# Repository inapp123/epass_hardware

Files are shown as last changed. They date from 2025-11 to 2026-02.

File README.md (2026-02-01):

# 明日方舟电子通行认证 PCB

一款类似手机游戏《明日方舟》中的通行认证的电子挂牌。

当前版本：Ver0.6

本项目存放通行认证的PCB电路设计。PCB为群友“你说得对”使用嘉立创EDA进行Layout。

USB布线比我的kicad好，而且只需要二层板。如果你需要查看原始kicad设计文件，请在左上角将分支切换为：onlykicad。

设计。工艺参数参考嘉立创二层板，设计厚度为1mm。

## 文件

* 阻容封装0402：
  * ProDoc__v0.6_0402_2026-01-24.epro2 PCB设计文件
  * InteractiveBOM_0.6_0402_2026-1-24.html 交互式BOM

* 阻容封装0603：
  * ProDoc__v0.6_0603_2026-01-24.epro2 PCB设计文件
  * InteractiveBOM_0.6_0603_2026-1-24.html 交互式BOM

**最新嘉立创专业版打开，不知道什么意思就打0603**

## BOM链接

感谢 星语Studio 整理！

0603版本：https://docs.qq.com/sheet/DTUNVSW9USXBOS3VJ?nlc=1&tab=8444d8
0402版本：https://docs.qq.com/sheet/DTUNVSW9USXBOS3VJ?nlc=1&tab=msd95g

## 开源协议

CERN Open Hardware Licence Version 2 - Permissive

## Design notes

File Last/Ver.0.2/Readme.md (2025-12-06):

# ⓘ 此为旧版本文件(ver0.2)

![[image-20251119004316917.png]]

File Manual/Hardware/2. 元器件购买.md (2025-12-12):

# 此文档用于解答关于元件购买的问题

## 按钮
2 * 4 * 3.5 小贝贝(指BOM表链接，若在别处购买请按照实际尺寸)
![[2_1.png]]

## 肖特基二极管
1N5819WS SS14 **SOD-323**

### ⚠务必注意封装是 SOD-323 (非常重要，已有N人买错)
![[2_2.png]]

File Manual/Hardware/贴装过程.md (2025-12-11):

# 电子通行证制作指南

版本：V0.3.1

## 在一切开始之前...
> 本项目包含QFN表面贴装器件，如果您此前没有使用表面贴装器件进行DIY项目的经验，建议您通过其他较简单的项目练习贴装，**不要直接开始制作**。

## 除了bom表中的器件外，应该准备的工具:

### 焊接工具

| 工具名称 | 说明 |
| --- | --- |
| 锡膏 | 锡膏温度不建议过高，使用熔点在173-213摄氏度之间的中温锡即可 |
| 锡丝 | 焊接直插器件时比锡膏舒服，建议熔点同上 |
| 助焊剂 | 弥补焊接技术不足的好工具，一般使用针管装smt焊油 |
| 洗板水 | 如果出现奇怪的短路问题，请使用洗板水洗干净pcb再测试，有条件的可以使用超声波清洗仪 |
| 电烙铁 | 一把正版的黄花电烙铁足矣，温度不宜过高，开在300度左右即可 |
| 热风枪 | 有条件最好选用868D(气泵式),858D(风扇式)加热不太均匀 |
| 加热台 | reserved |
| 镊子 | 为了舒服地贴装，最好有直头镊子和弯头镊子，镊子可能被助焊剂污染，当镊子明显与器件粘连时，用酒精和洗板水清洗镊尖 |
| 放大镜 | 最好是玻璃放大镜，帮你看清微小的焊点 |
| 吸锡带 | 当焊盘上出现了过多的锡，使用它去除。你也可以使用吸锡器，但是需要一些练习 |
| 高温胶带 | 保护/绝缘/临时固定，pcb上的万用胶带 |
| *漆包线 | 非必选项，但是遇到意外时它很有用 |

### 调试工具

| 工具名称 | 说明 |
| --- | ----- |
| 万用表 | reserved |
| USB转串口 | 没有此工具将无法在屏幕不工作的状态下调试设备 |

### 开始贴装之前...

* 本项目包含的器件体积较小，因此对于很多小型器件，不要加入大量的锡，否则可能会短路。对于0603器件，轻按针管挤出一点点锡到焊盘上即可。
* 遇到引脚较密集的器件，合理使用助焊剂增加锡融化后的表面张力让焊接变得方便。
* 不要使用过高的温度/过长的时间/局部加热焊接芯片，连接器等温度敏感器件，焊接时匀速顺时针/逆时针均匀加热器件。
* 如果无法使用烙铁焊接贴片器件就使用风枪焊接，不要强行焊接导致焊盘脱落。
* 使用镀锡pcb板时，请不要提前开封pcb，否则可能导致焊盘氧化导致大量虚焊。

## 贴装

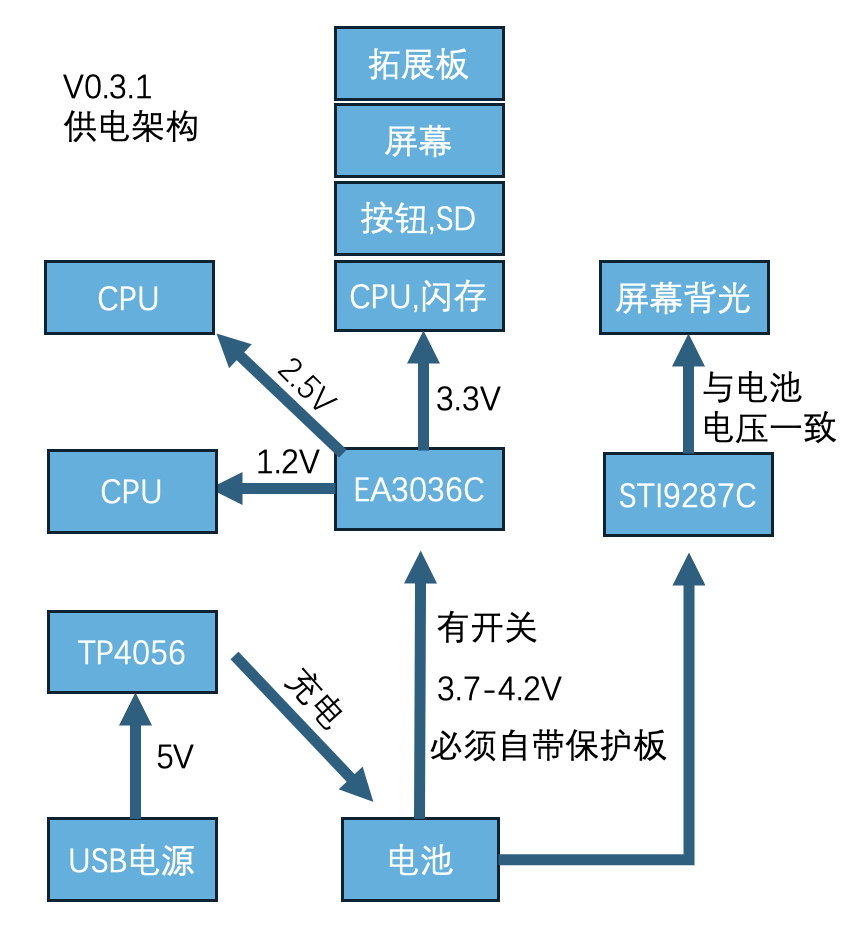
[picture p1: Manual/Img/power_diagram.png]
V0.3.1 电源架构


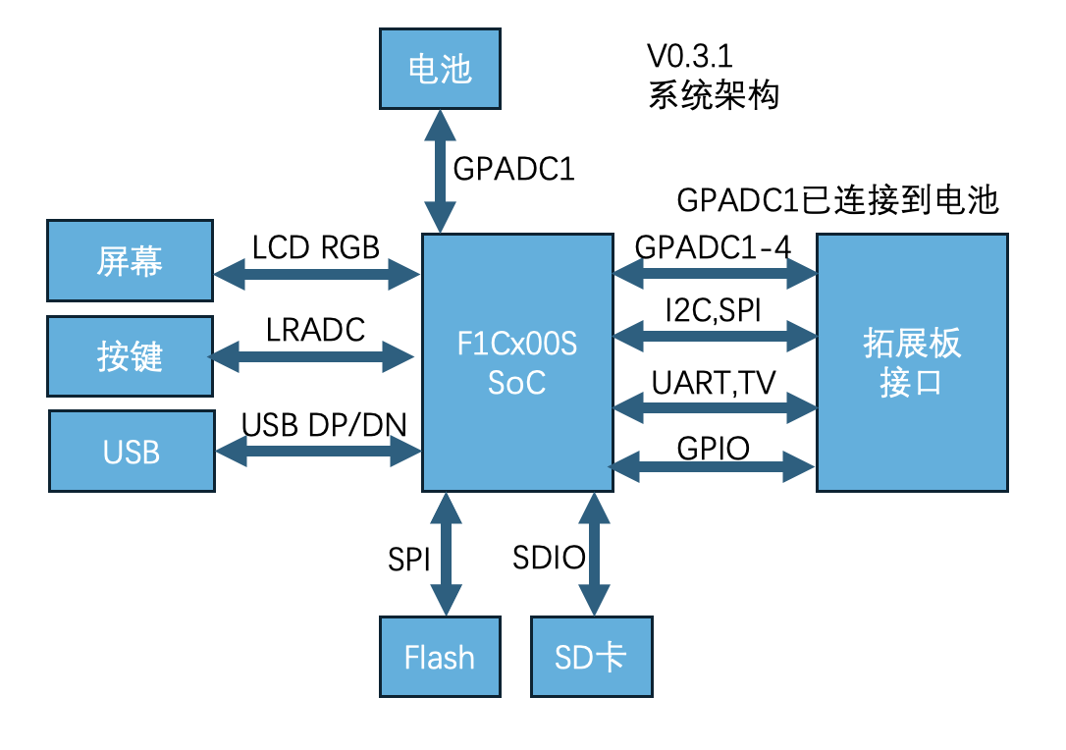
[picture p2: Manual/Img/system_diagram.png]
V0.3.1 系统架构


上图展示了此版本电子通行证的主要构成模块，贴装遵循先供电，后核心，最后外设顺序进行。

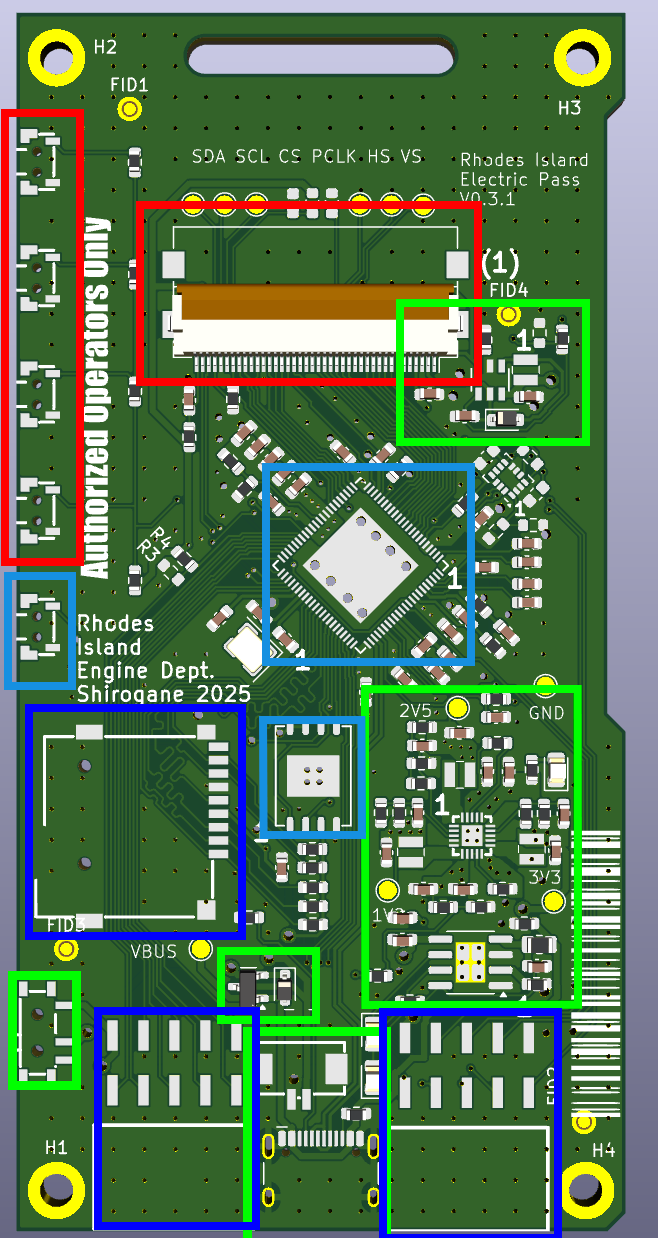
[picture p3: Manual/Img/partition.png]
PCB上大致器件功能分类(具体贴装请参考原理图)


上图大致框出了各类器件，贴装过程按绿色，浅蓝色，红色，深蓝色顺序进行，若前一部分故障未调试完毕请不要贴装下一部分器件以免产生不确定因素干扰调试！

>绿色框选部分及其外围器件为供电器件，必须先行贴装。贴装后必须上电测试各路供电输出电压以及是否短路！

大量复刻案例由于电源器件虚焊导致电压超标，此时未测试即贴装其他器件可能烧毁器件！！！各路电压输出正常则说明绿色部分贴装完成。

>浅蓝色框选部分及其外围器件为核心器件，在电源测试通过后贴装，该类别器件引脚细密集成度高，需注意防静电防过热防虚焊。

该部分贴装后即可使用usb接口进行联机测试并烧录固件，此时使用usb串口转换器观察其状态，若能正常进入系统则说明蓝色部分贴装完成。

>红色框选部分及其外围器件为屏幕连接器及用户按钮，此类别器件大多为塑料件，需注意防过热。

该部分贴装后即可插入屏幕进行最终测试，若屏幕正常显示可拷入干员视频资源测试按钮工作状态，按钮工作正常则说明红色部分贴装完成。

>深蓝色部分为扩展板连接器和sd卡连接器，若不需要使用扩展版和/或sd卡可不贴装。

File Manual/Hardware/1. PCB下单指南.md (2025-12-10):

## ⓘ 以嘉立创下单助手（桌面端）为例
*   **进入主页** → **PCB下单** 
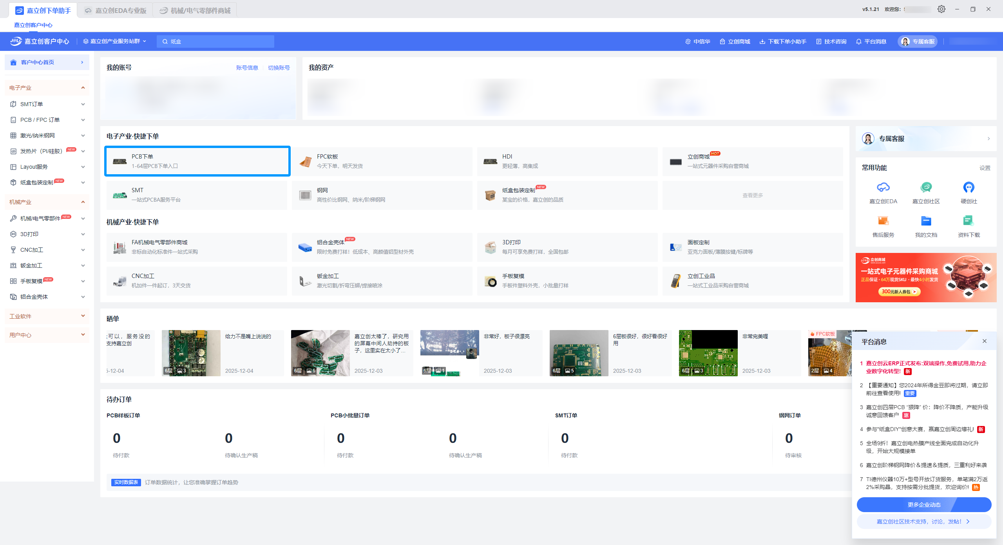
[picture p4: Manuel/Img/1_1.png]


> **ⓘ 以Gerber文件为例**
* 点击 上传PCB
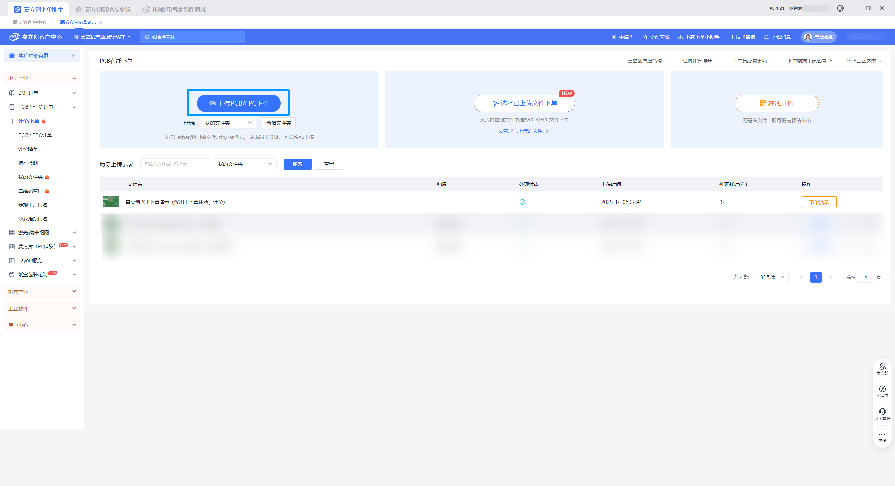
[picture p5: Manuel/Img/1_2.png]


* 选取你所下载的Gerber文件(请以实际文件名为准，此处仅为示例)
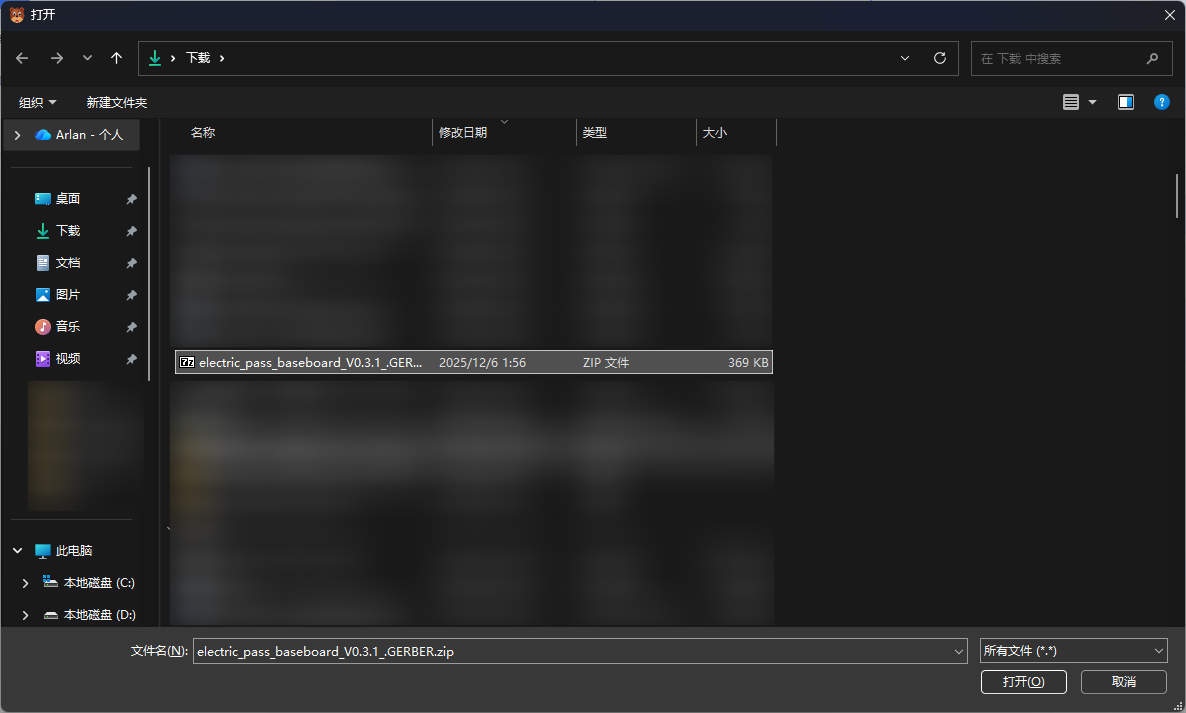
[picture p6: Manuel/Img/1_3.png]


* 在解析完成后点击 立即下单
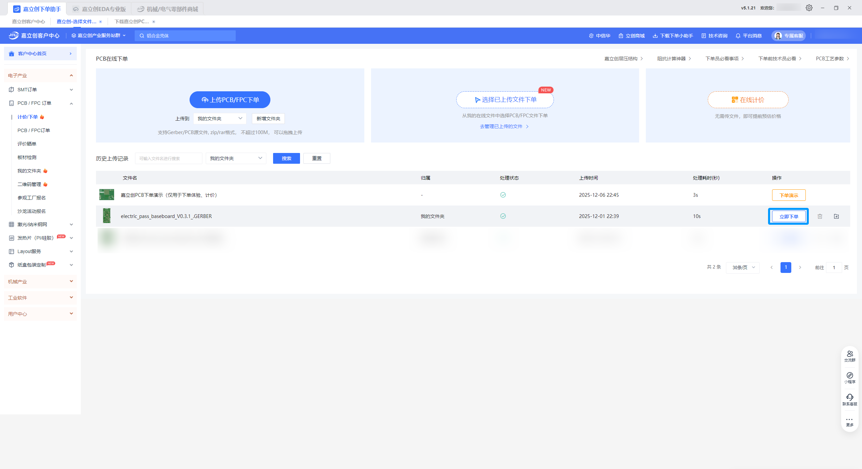
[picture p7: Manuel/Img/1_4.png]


## ⚠ 请注意：以下的所以参数为默认情况，若版本文档有详细指明请使用版本文档中的数据

* 选择材料并补充信息

| 步骤  | 选项名称  | 默认选项 | 备注 |
| --- | ----- | --- | --- |
| 1 | 材料 | FR4 | / |
| 2 | 尺寸 | * 自动识别 | 若没有成功识别请在交流群群中询问 |
| 3 | 板子数量  | / | 随心所欲，想做多少块订多少个，建议留出几个备用 |
| 4 | 板子层数  | 2 | / |
| 5 | 确认生产稿 | 不需要 | / |
| 6 | 出货方式  | 单片 | / |
| 7 | 板上加标志 | / | 随心所欲，但部分选项需要收费 |
| 8 | SMT贴片 | 不需要 | 除非你付得起SMT高昂的开机费用 |
| 9 | 钢网 | 不需要 | TB定做似乎更便宜...... |
其他信息（开票&资料&快递自己选即可）
* 点击提交订单后等待审核完成付款生产即可

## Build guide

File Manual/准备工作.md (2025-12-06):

## 你需要的工具

| 名称 | 型号  | 备注 |
| --- | --- | --- |
| 电烙铁 | T12 | 可控温，最便宜的那种就行，功率至少30W  |
| 烙铁头 | 刀头  | 对自己好点，买个好使的 |
| 锡浆 | / | / |
| 焊锡丝 | / | / |
| 助焊剂 | / | / |
| 加热台 | / | 将军说过 ✍加热台一定要能控温 |
| 镊子 | / | 买三把的套件，自己看哪种合适 |
| 串口调试工具 | / | CH34X |
| 万用表 | / | 调试用 买个最便宜的有电压档和导通挡的就行 |
## 下载所需文件 
你可以在 release 中下载所需文件
[Release](https://github.com/inapp123/epass_hardware/releases)
### 你至少需要
* BOM  "electric_pass_baseboard_V#.#.#_ .BOM.html"" 
* PCB(Gerber) "electric_pass_baseboard_V0.3.1_.GERBER.zip"
* Firmware 详见关于软件的手册(事实上是根本还没写😅)

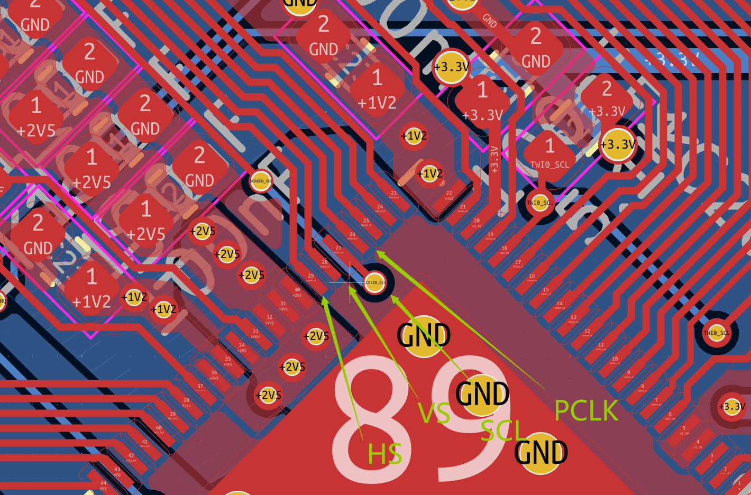
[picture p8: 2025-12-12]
Manual/Img/2_11.png

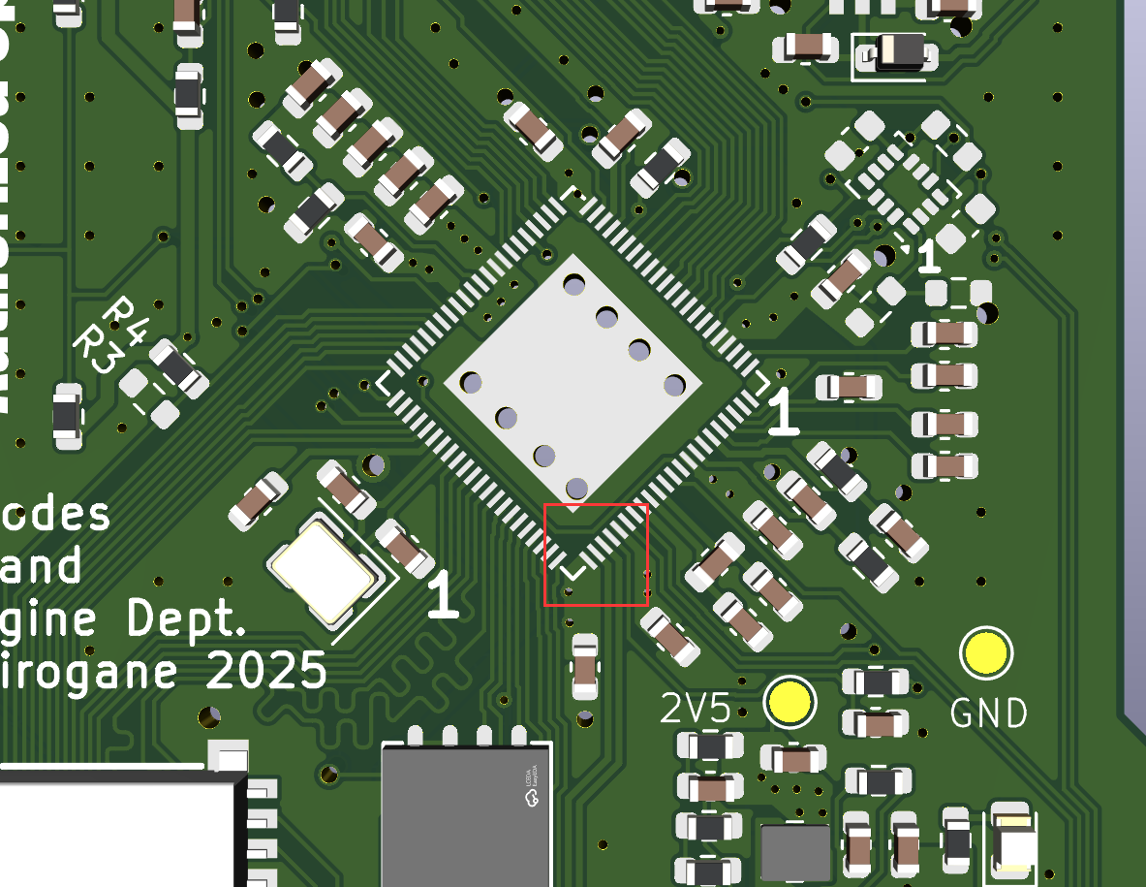
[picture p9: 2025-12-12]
Manual/Img/2_5.png

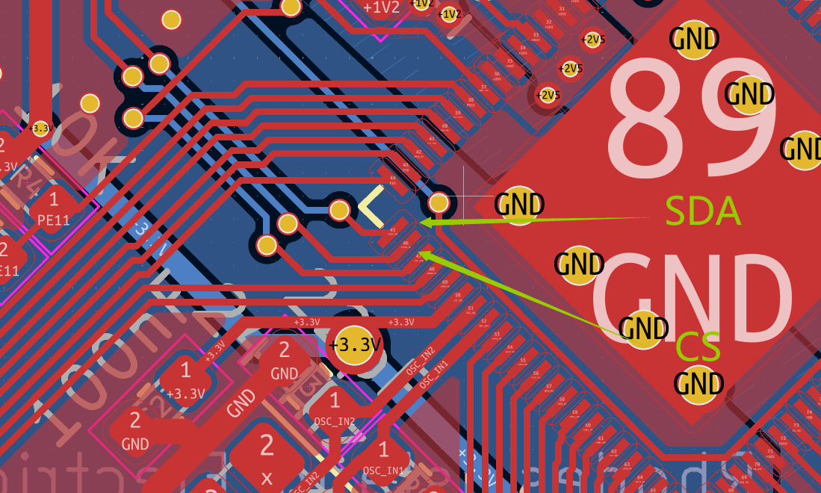
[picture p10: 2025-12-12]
Manual/Img/2_12.png

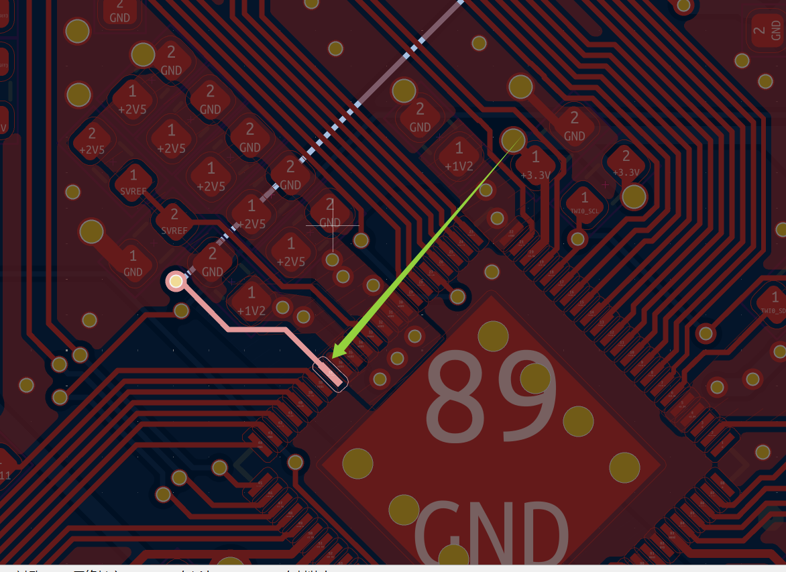
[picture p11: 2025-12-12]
Manual/Img/2_13.png

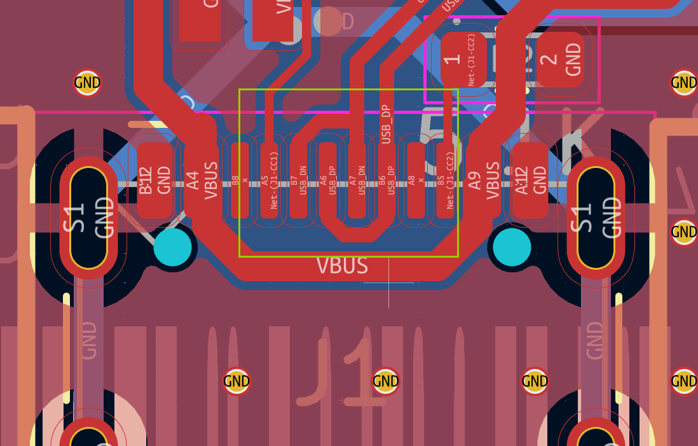
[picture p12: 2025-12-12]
Manual/Img/2_4.png

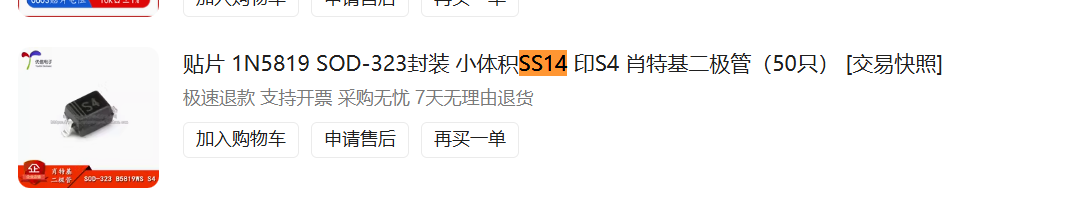
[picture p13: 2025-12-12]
Manual/Img/2_2.png

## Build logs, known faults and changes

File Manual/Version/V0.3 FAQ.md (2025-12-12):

# 此文档用于对于0.3版本的疑难解答

## ⓘ 文档整理 @白银

> **特别感谢 粉色妖精小姐♪ ✾爱莉希雅♪**

# 正文
>感谢您的复刻！如果您也踩到了坑，欢迎来这边一起共享经验，非常感谢您的参与！

## 1. 没有短路，三路供电没有全部出完 或者电压不对
> 电压变高一般是反馈脚没接好 没有电压就很多种可能了（）总之基本可能是虚焊
### 解决
* 补焊EA3036全部引脚，尤其是对应侧
![[2_3.png]]

* 更换EA3036

## 2. 不短路，供电全出，连上电脑后提示42/43 Device failed to start
### 解决：检查DP-DN信号
#### ① 检查USB Type-C是否虚焊,是否连锡
![[2_4.png]]
>如何检查短路 ：可以找一根不用的C口数据线 剪掉头，测量里面的两根信号线之间有没有短路
#### ② 检查主控USB引脚是否虚焊
![[2_5.png]]
## 3. 三路供电对地不导通，两两不导通，但是上电直接大电流，电源灯不亮
### 解决：
#### ① 拆焊屏幕背光芯片，再次上电，若正常则检查屏幕背光区域是否焊接错误
![[2_6.png]]

#### ② 检查二极管是否焊反，有横线的一端为负极。电压高的一端为正极。正极对应PCB丝印开口(没画横线)的一端

![[2_7.png]]‘
## 4.  烧录过程中中断，但是芯片已经有底层数据，导致无法进入下载模式重新烧录
#### 解决：参考这个程序刷新教程,1分钟处

[BiliBili♿](https://www.bilibili.com/video/BV1Xu28BDEjL/)

（很明显，我和白银都懒得写了（超级小声））

## 5. 烧录程序，提示The spi nand flash '0x00000000' is not yet supported
>f1c没认到flash芯片

![[2_8.png]]

### 解决：

#### 检查NAND区域引脚是否虚焊

![[2_8.png]]

#### 解决：检查NAND区域引脚是否虚焊
![[2_9.png]]
## 6. 烧录完成后屏幕不显示
### 解决
#### ① 1.  先看看背光有没有亮起来，有没有“闪一下”（这个视频里 10分钟位置的表现[https://www.bilibili.com/video/BV1QaSBBUE43](https://www.bilibili.com/video/BV1QaSBBUE43) ）（芯片正常工作的表现）
##### A 如有（和上述视频一样）
![[2_10.png]]

###### Ⅰ. 断电检查屏幕6个关键信号点两两没有短路
##### Ⅱ. 开机检查屏幕6个关键信号点电压(值如下)

| point |  U |
| :---: | :--: |
|  sda  | 3.3V |
|  scl  |  2v  |
|  cs | 3.3v |
| pclk  | 1.6V |
|  hs | 3.3V |
|  VS | 3.3V |

**哪一路没有就加焊那一路（F1C)**

![[2_11.png]]

![[2_12.png]]

## 7. 亮度调节不了，一直是最亮状态，没有变化
>检查SCREEN_BL_CTRL脚有没有虚焊

![[2_13.png]]
## 8. 屏幕显示异常，包括但不限于颜色错误
>颜色线可能虚焊了

![[2_14.png]]

# 奇奇怪怪的问题
## 1. 天选6Pro AMD版 右侧USB接口可能会出现USB报错43

>可能由于USB总线结构问题，即使焊接正常，USB也会报错代码43 可以换到左边（针对天选6Pro：电源侧）的USB-A 其他AMD设备目前不知道会不会出现相同问题，AMD用户可以尝试试试所有USB接口

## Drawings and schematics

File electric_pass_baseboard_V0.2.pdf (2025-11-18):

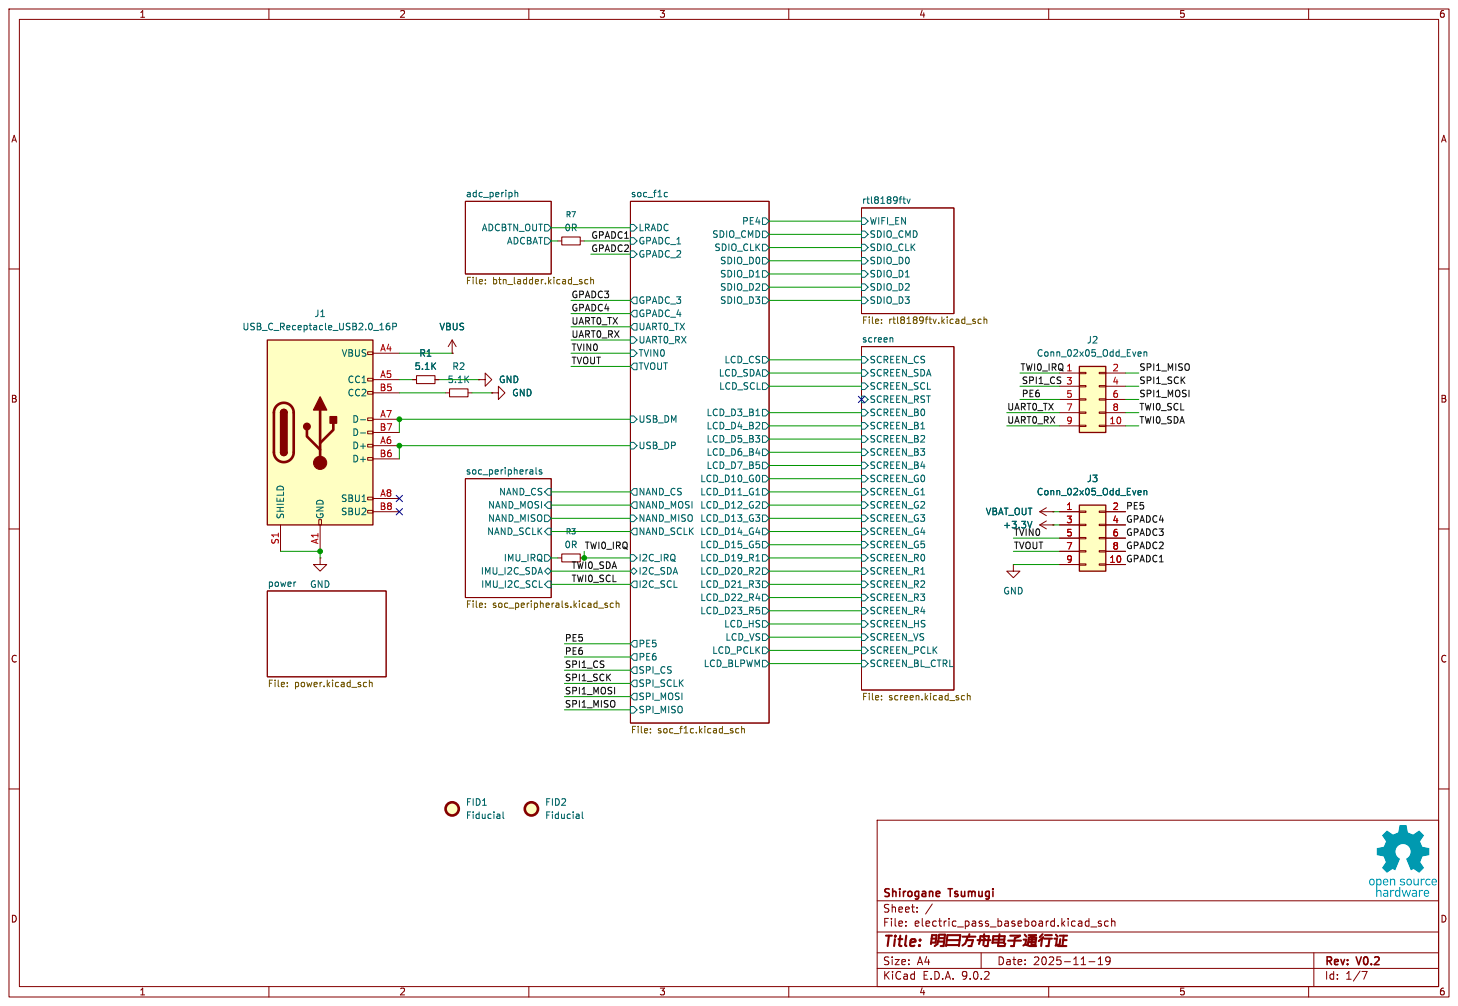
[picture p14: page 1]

Id: 1/7 Title: þÿfeåe¹‚u5[P•ˆL‹Á

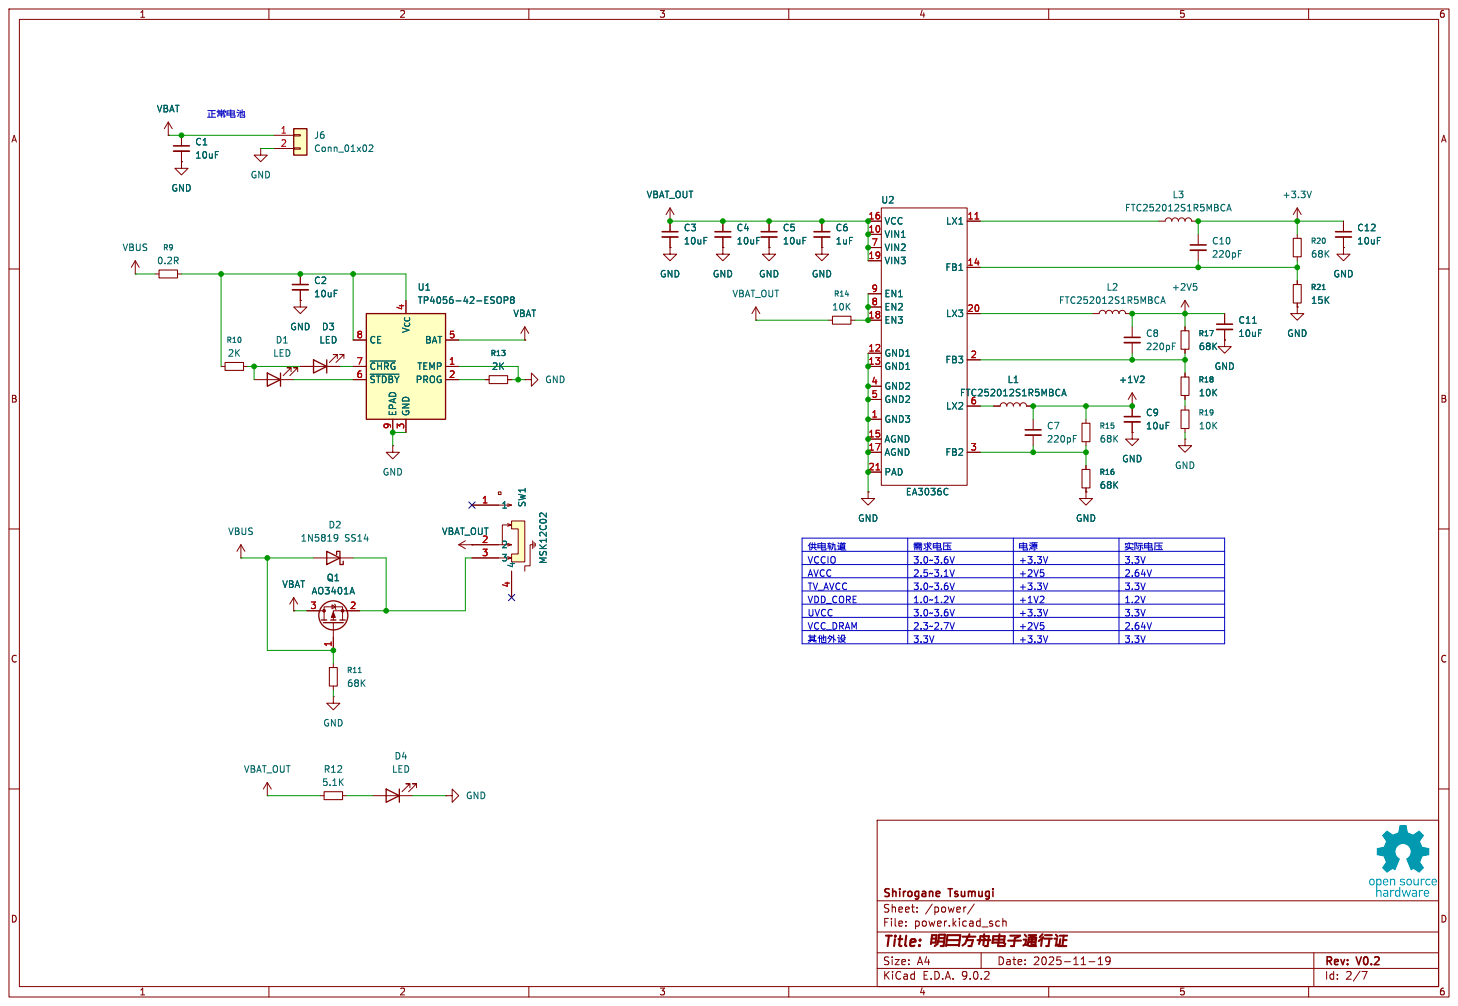
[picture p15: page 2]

File: power.kicad_sch Sheet: /power/
Id: 2/7 Title: þÿfeåe¹‚u5[P•ˆL‹Á

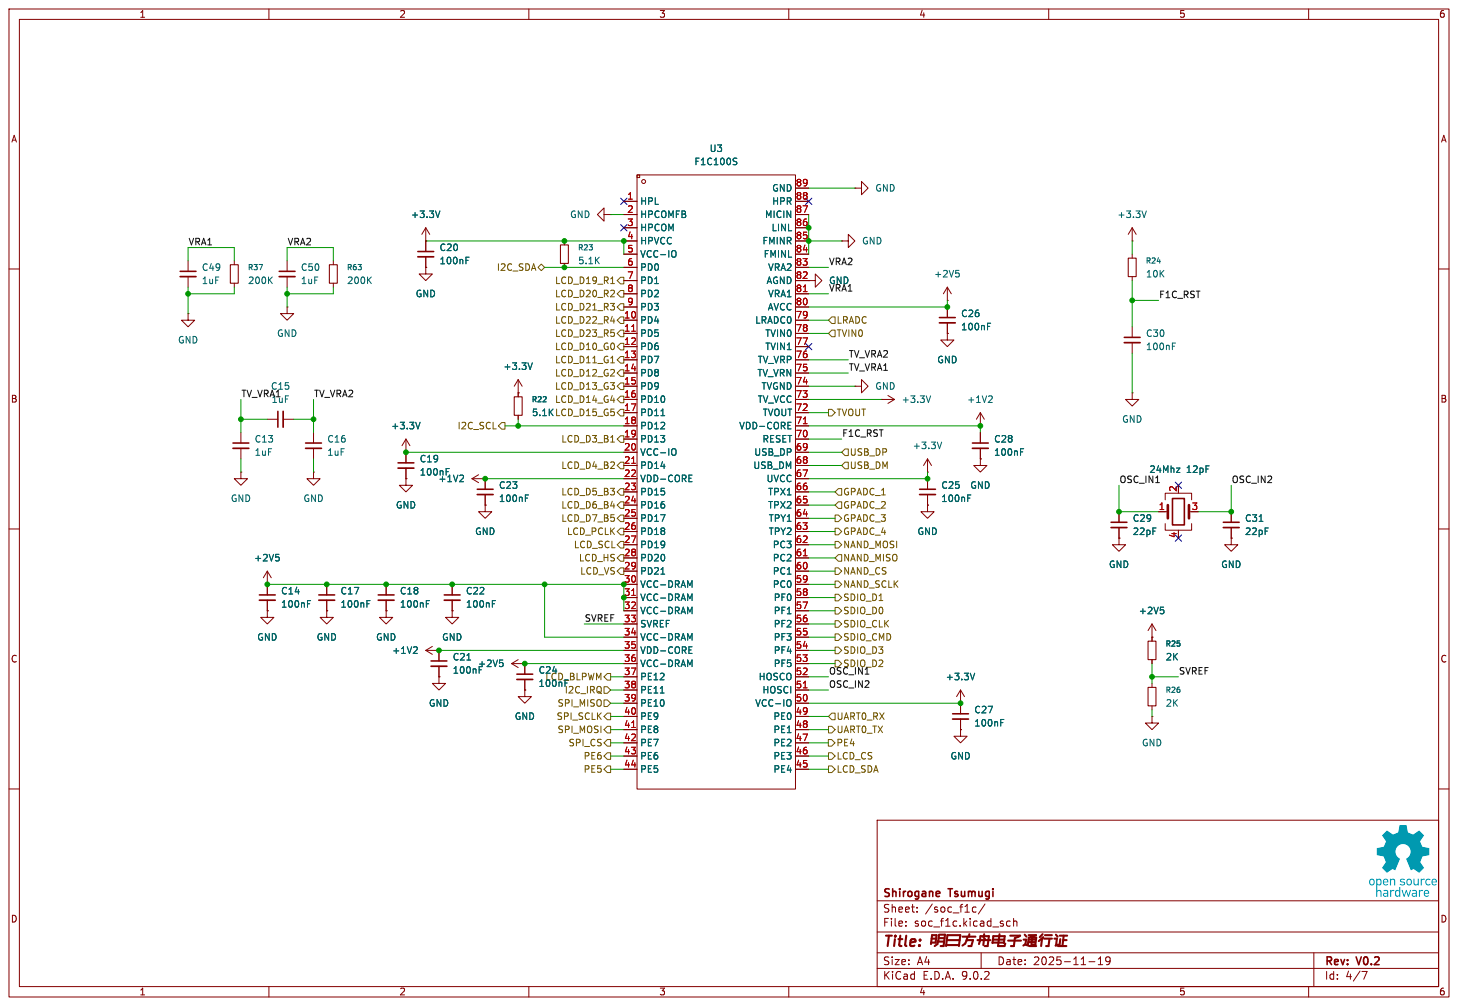
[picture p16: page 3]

File: soc_f1c.kicad_sch Sheet: /soc_f1c/
Id: 4/7 Title: þÿfeåe¹‚u5[P•ˆL‹Á

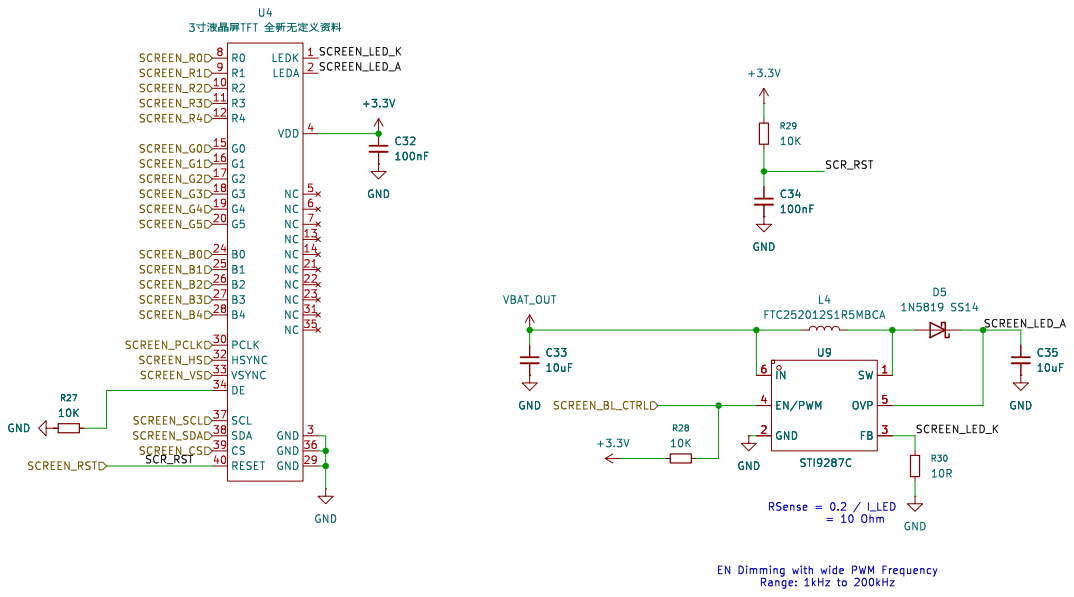
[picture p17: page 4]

þÿ3[øm²fv\OTFTþÿQhe°eà[šNI•De™

EN Dimming with wide PWM Frequency

Id: 4/7 Title: þÿfeåe¹‚u5[P•ˆL‹Á

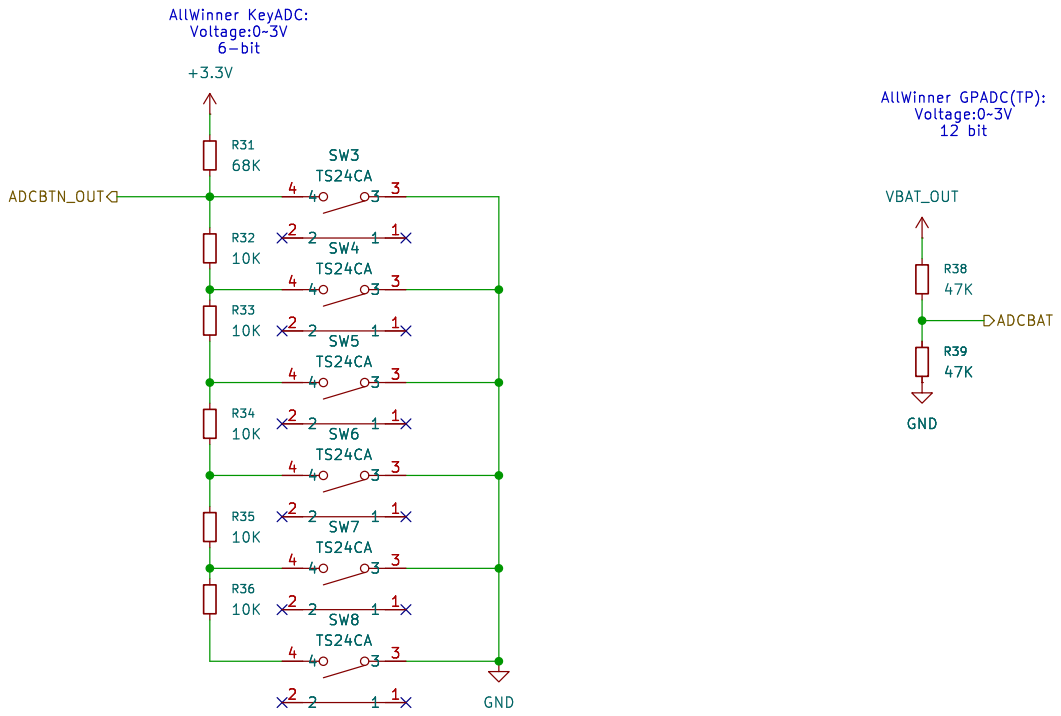
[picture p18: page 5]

File: btn_ladder.kicad_sch Sheet: /adc_periph/
Id: 5/7 Title: þÿfeåe¹‚u5[P•ˆL‹Á

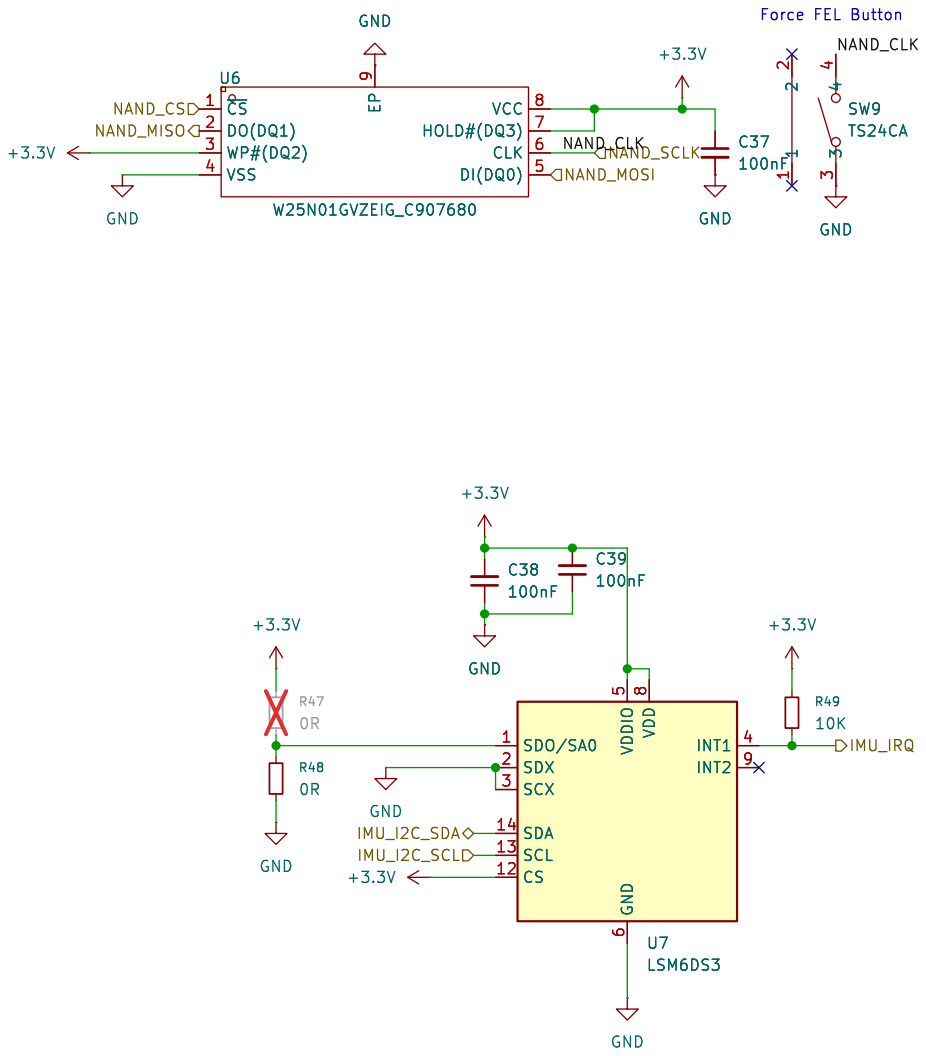
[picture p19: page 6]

9 VCC 8 HOLD#(DQ3) 7 CLK 6 DI(DQ0) 5 U6 W25N01GVZEIG_C907680 GNDGND

9 VCC 8 HOLD#(DQ3) 7 CLK 6 DI(DQ0) 5 GND

File: soc_peripherals.kicad_sch Sheet: /soc_peripherals/
Id: 6/7 Title: þÿfeåe¹‚u5[P•ˆL‹Á

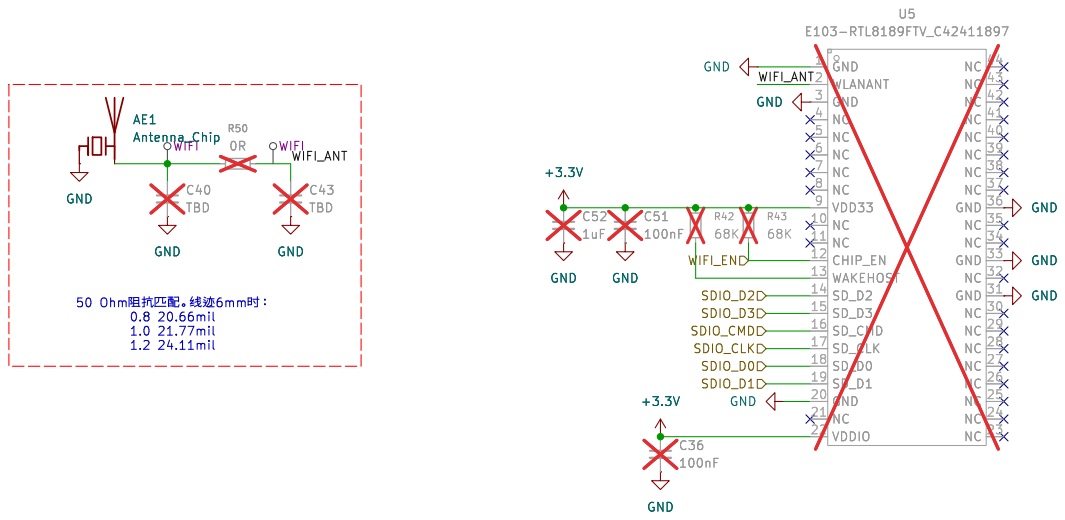
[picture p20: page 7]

Id: 8/7 Title: þÿfeåe¹‚u5[P•ˆL‹Á

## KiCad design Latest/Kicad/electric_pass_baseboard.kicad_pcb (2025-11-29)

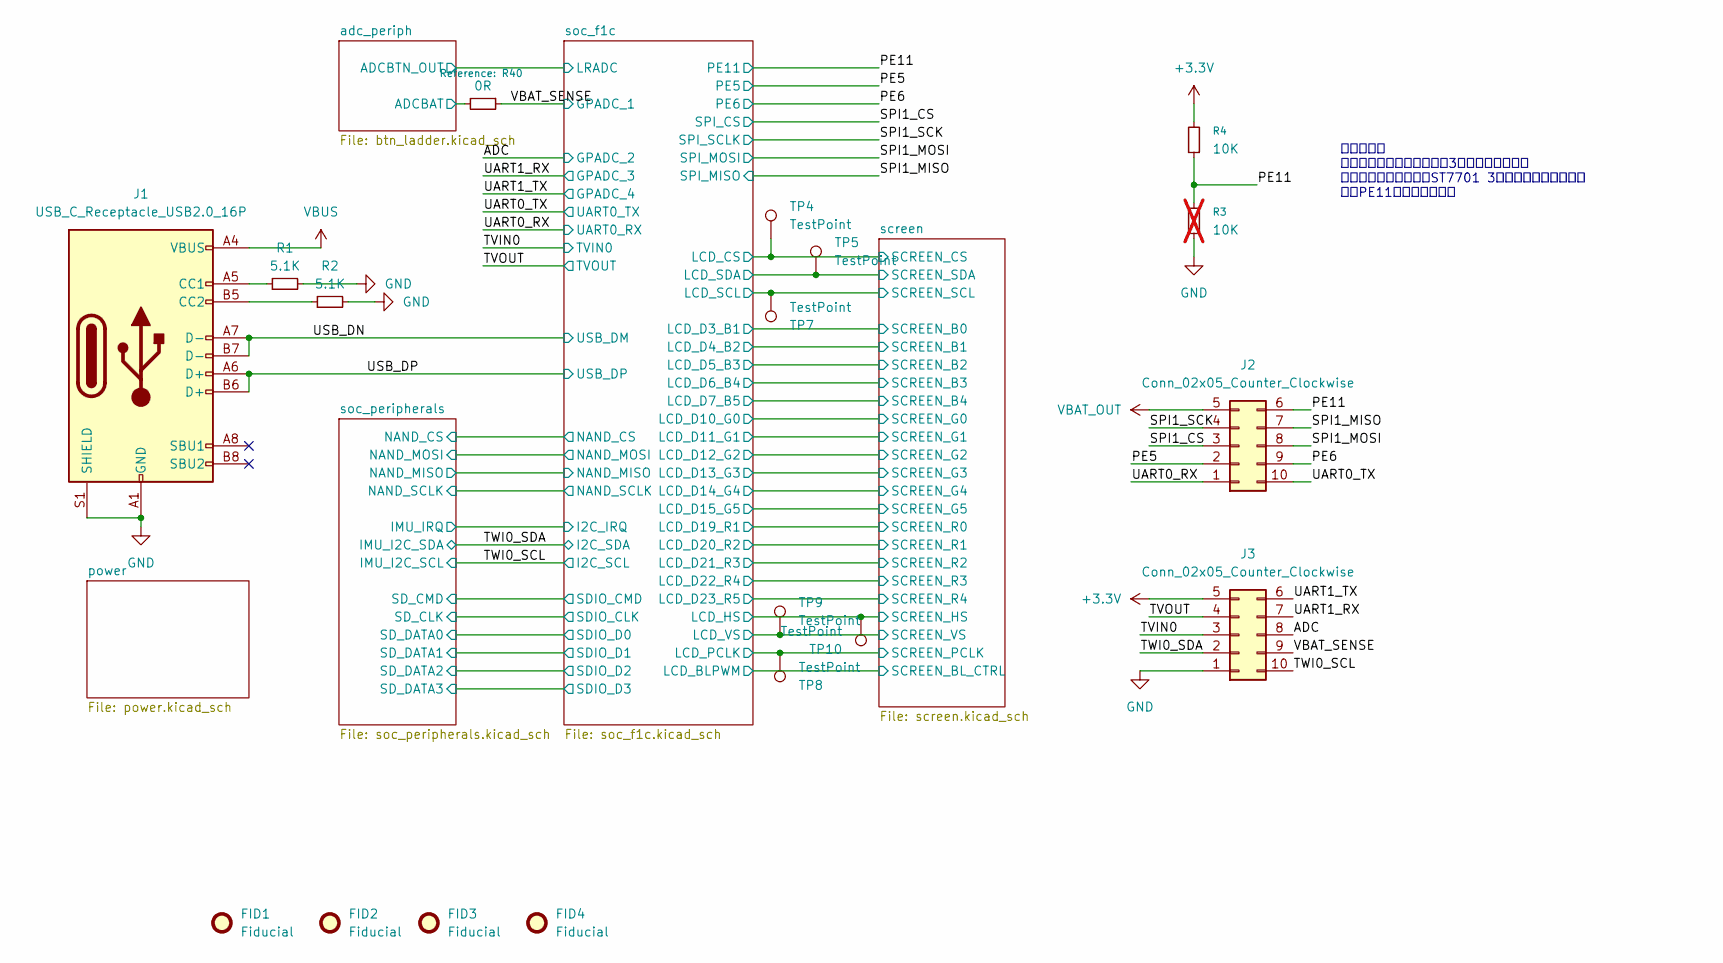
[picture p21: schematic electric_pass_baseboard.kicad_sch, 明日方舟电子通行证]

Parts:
FID1, FID2, FID3, FID4: Fiducial; Fiducial_1mm_Mask2mm
J1: USB_C_Receptacle_USB2.0_16P; USB_C_Receptacle_HCTL_HC-TYPE-C-16P-01A
J2, J3: Conn_02x05_Counter_Clockwise; HDR-SMD_10P-P2.54-H-F-R2-C5-W8.5
R1, R2: 5.1K; R_0603_1608Metric
R3: 10K; R_0603_1608Metric; not fitted
R4: 10K; R_0603_1608Metric
R40: 0R; R_0603_1608Metric
TP4, TP5, TP7, TP8, TP9, TP10: TestPoint; TestPoint_Pad_D1.5mm

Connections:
+3.3V: J3.5, R4.2; also elsewhere on the board
/ADC: J3.8; also elsewhere on the board
/PE5: J2.2; also elsewhere on the board
/PE6: J2.9; also elsewhere on the board
/PE11: J2.6, R3.2, R4.1; also elsewhere on the board
/SPI1_CS: J2.3; also elsewhere on the board
/SPI1_MISO: J2.7; also elsewhere on the board
/SPI1_MOSI: J2.8; also elsewhere on the board
/SPI1_SCK: J2.4; also elsewhere on the board
/TVIN0: J3.3; also elsewhere on the board
/TVOUT: J3.4; also elsewhere on the board
/TWI0_SCL: J3.10; also elsewhere on the board
/TWI0_SDA: J3.2; also elsewhere on the board
/UART0_RX: J2.1; also elsewhere on the board
/UART0_TX: J2.10; also elsewhere on the board
/UART1_RX: J3.7; also elsewhere on the board
/UART1_TX: J3.6; also elsewhere on the board
/USB_DN: J1.A7 (D-), J1.B7 (D-); also elsewhere on the board
/USB_DP: J1.A6 (D+), J1.B6 (D+); also elsewhere on the board
/VBAT_SENSE: J3.9, R40.1; also elsewhere on the board
/adc_periph/ADCBAT: R40.2; also elsewhere on the board
/screen/SCREEN_CS: TP4.1; also elsewhere on the board
/screen/SCREEN_HS: TP10.1; also elsewhere on the board
/screen/SCREEN_PCLK: TP8.1; also elsewhere on the board
/screen/SCREEN_SCL: TP7.1; also elsewhere on the board
/screen/SCREEN_SDA: TP5.1; also elsewhere on the board
/screen/SCREEN_VS: TP9.1; also elsewhere on the board
GND: J1.A1 (GND), J1.A12 (GND), J1.B1 (GND), J1.B12 (GND), J1.S1 (SHIELD), J3.1, R1.2, R2.2, R3.1; also elsewhere on the board
unnamed: J1.A5 (CC1), R1.1
unnamed: J1.B5 (CC2), R2.1
VBAT_OUT: J2.5; also elsewhere on the board
VBUS: J1.A4 (VBUS), J1.A9 (VBUS), J1.B4 (VBUS), J1.B9 (VBUS); also elsewhere on the board

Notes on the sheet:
配置电阻： 若购买的屏幕是老王电子的3元屏，此处上拉。 若购买的屏幕是通用的ST7701 3寸钢壳屏，此处下拉。 因此PE11请尽量用于输出

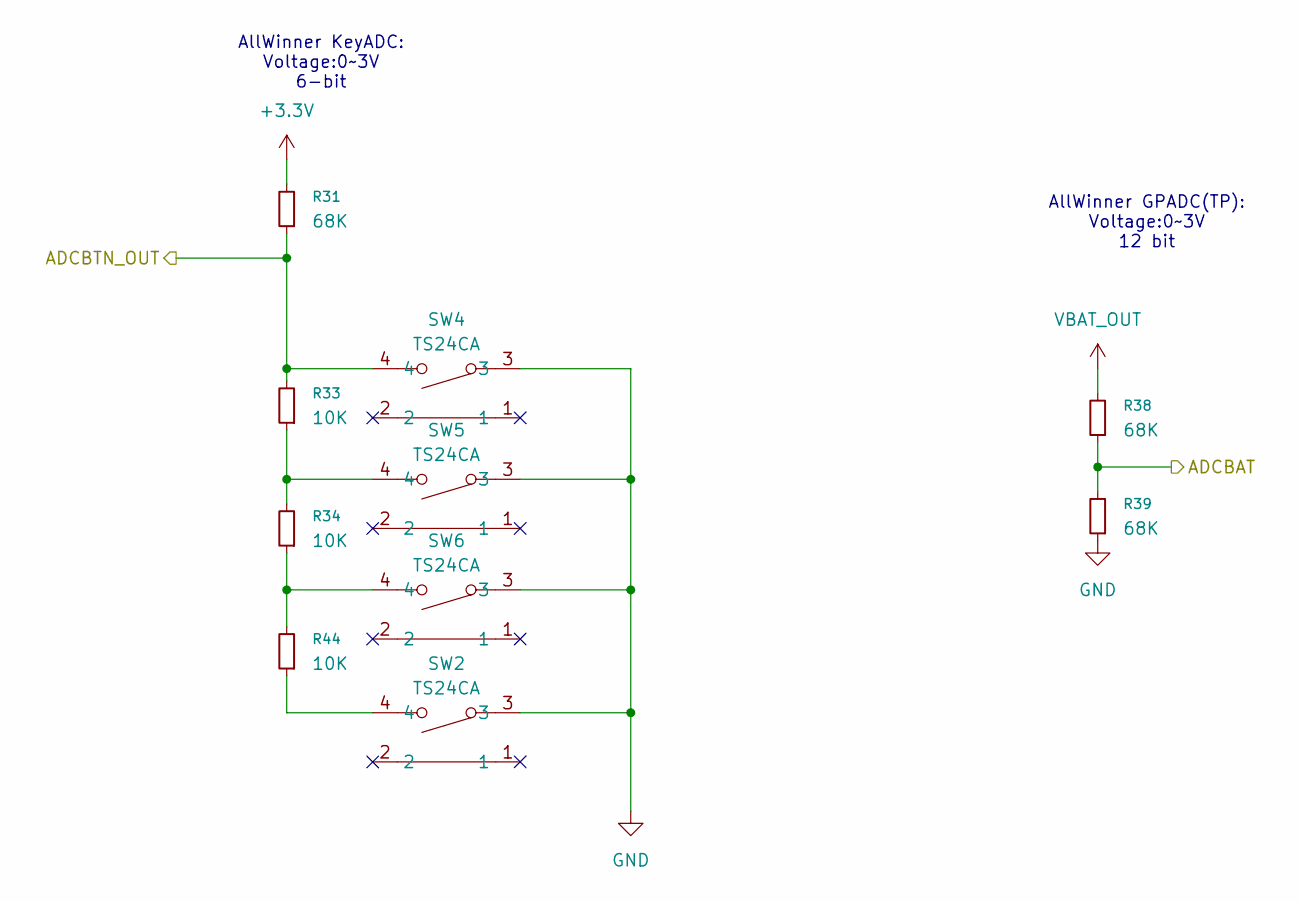
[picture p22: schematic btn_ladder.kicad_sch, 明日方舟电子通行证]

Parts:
R31, R38, R39: 68K; R_0603_1608Metric
R33, R34, R44: 10K; R_0603_1608Metric
SW2, SW4, SW5, SW6: TS24CA; SW-SMD_TS24CA; LCSC Part C393942

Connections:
+3.3V: R31.2; also elsewhere on the board
/adc_periph/ADCBAT: R38.1, R39.2; also elsewhere on the board
/adc_periph/ADCBTN_OUT: R31.1, R33.2, SW4.4; also elsewhere on the board
GND: R39.1, SW2.3, SW4.3, SW5.3, SW6.3; also elsewhere on the board
unnamed: R33.1, R34.2, SW5.4
unnamed: R34.1, R44.2, SW6.4
unnamed: R44.1, SW2.4
VBAT_OUT: R38.2; also elsewhere on the board

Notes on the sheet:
AllWinner KeyADC: Voltage:0~3V 6-bit
AllWinner GPADC(TP): Voltage:0~3V 12 bit

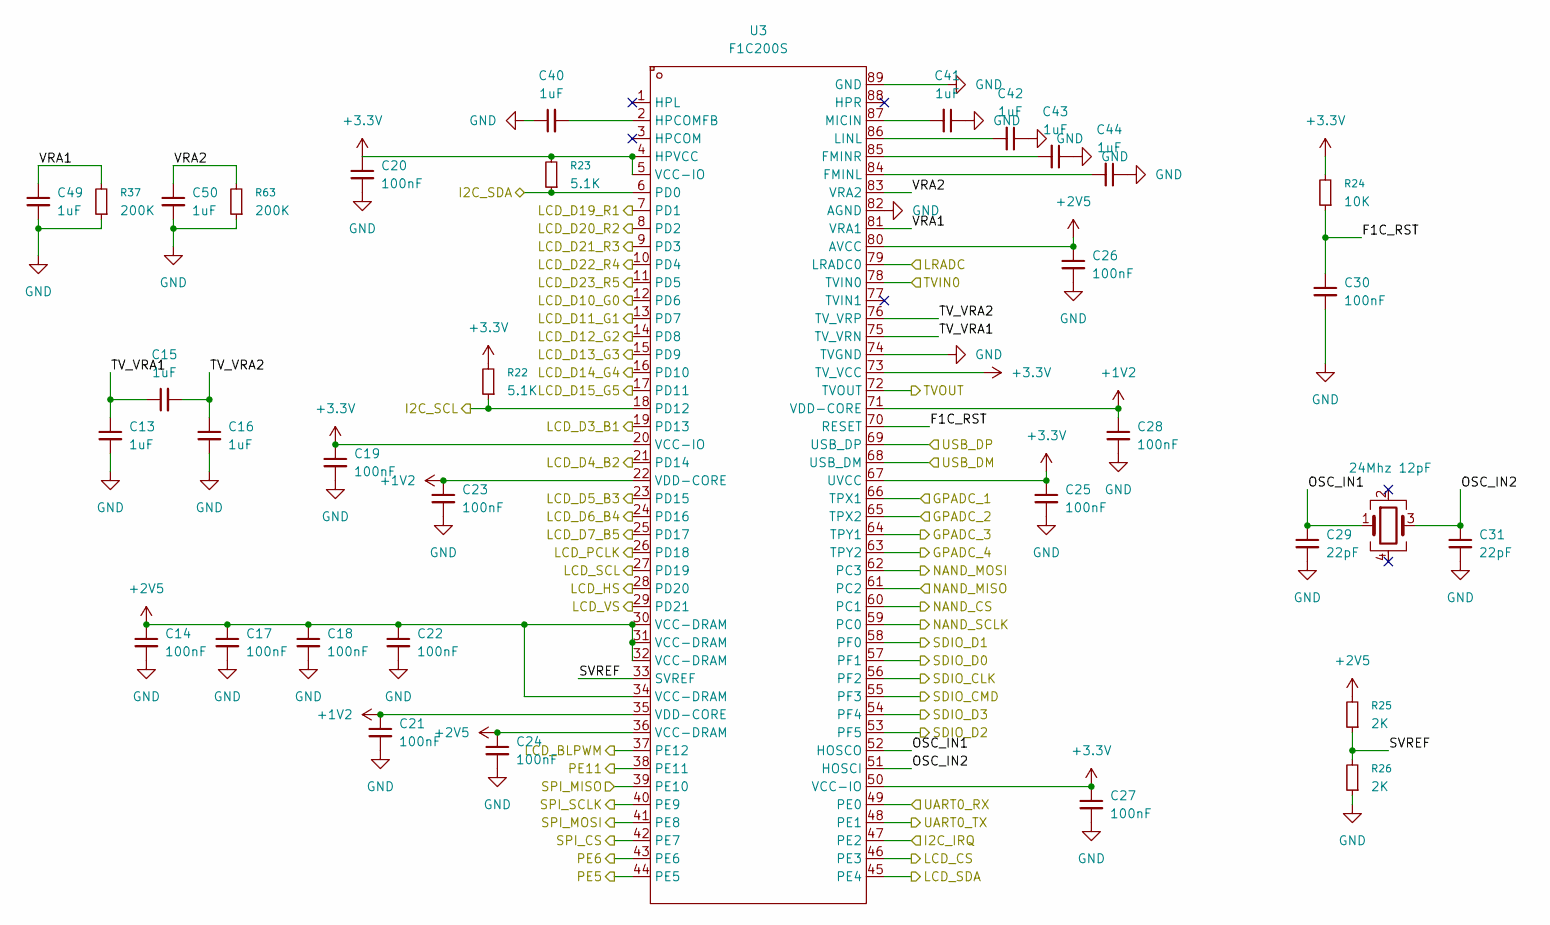
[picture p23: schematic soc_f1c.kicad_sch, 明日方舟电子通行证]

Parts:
C13, C15, C16, C40, C41, C42, C43, C44, C49, C50: 1uF; C_0603_1608Metric
C14, C17, C18, C19, C20, C21, C22, C23, C24, C25, C26, C27, C28, C30: 100nF; C_0603_1608Metric
C29, C31: 22pF; C_0603_1608Metric
R22, R23: 5.1K; R_0603_1608Metric
R24: 10K; R_0603_1608Metric
R25, R26: 2K; R_0603_1608Metric
R37, R63: 200K; R_0603_1608Metric
U3: F1C200S; QFN-88_L10.0-W10.0-P0.40-BL-EP6.75; LCSC Part C1511928
Y1: 24Mhz 12pF; Crystal_SMD_3225-4Pin_3.2x2.5mm

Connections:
+1V2: C21.1, C23.1, C28.1, U3.22 (VDD-CORE), U3.35 (VDD-CORE), U3.71 (VDD-CORE); also elsewhere on the board
+2V5: C14.1, C17.1, C18.1, C22.1, C24.1, C26.1, R25.2, U3.30 (VCC-DRAM), U3.31 (VCC-DRAM), U3.32 (VCC-DRAM), U3.34 (VCC-DRAM), U3.36 (VCC-DRAM), U3.80 (AVCC); also elsewhere on the board
+3.3V: C19.1, C20.1, C25.1, C27.1, R22.2, R23.2, R24.2, U3.4 (HPVCC), U3.5 (VCC-IO), U3.20 (VCC-IO), U3.50 (VCC-IO), U3.67 (UVCC), U3.73 (TV_VCC); also elsewhere on the board
/ADC: U3.65 (TPX2); also elsewhere on the board
/PE5: U3.44 (PE5); also elsewhere on the board
/PE6: U3.43 (PE6); also elsewhere on the board
/PE11: U3.38 (PE11); also elsewhere on the board
/SPI1_CS: U3.42 (PE7); also elsewhere on the board
/SPI1_MISO: U3.39 (PE10); also elsewhere on the board
/SPI1_MOSI: U3.41 (PE8); also elsewhere on the board
/SPI1_SCK: U3.40 (PE9); also elsewhere on the board
/TVIN0: U3.78 (TVIN0); also elsewhere on the board
/TVOUT: U3.72 (TVOUT); also elsewhere on the board
/TWI0_SCL: R22.1, U3.18 (PD12); also elsewhere on the board
/TWI0_SDA: R23.1, U3.6 (PD0); also elsewhere on the board
/UART0_RX: U3.49 (PE0); also elsewhere on the board
/UART0_TX: U3.48 (PE1); also elsewhere on the board
/UART1_RX: U3.64 (TPY1); also elsewhere on the board
/UART1_TX: U3.63 (TPY2); also elsewhere on the board
/USB_DN: U3.68 (USB_DM); also elsewhere on the board
/USB_DP: U3.69 (USB_DP); also elsewhere on the board
/VBAT_SENSE: U3.66 (TPX1); also elsewhere on the board
/adc_periph/ADCBTN_OUT: U3.79 (LRADC0); also elsewhere on the board
/screen/SCREEN_B0: U3.19 (PD13); also elsewhere on the board
/screen/SCREEN_B1: U3.21 (PD14); also elsewhere on the board
/screen/SCREEN_B2: U3.23 (PD15); also elsewhere on the board
/screen/SCREEN_B3: U3.24 (PD16); also elsewhere on the board
/screen/SCREEN_B4: U3.25 (PD17); also elsewhere on the board
/screen/SCREEN_BL_CTRL: U3.37 (PE12); also elsewhere on the board
/screen/SCREEN_CS: U3.46 (PE3); also elsewhere on the board
/screen/SCREEN_G0: U3.12 (PD6); also elsewhere on the board
/screen/SCREEN_G1: U3.13 (PD7); also elsewhere on the board
/screen/SCREEN_G2: U3.14 (PD8); also elsewhere on the board
/screen/SCREEN_G3: U3.15 (PD9); also elsewhere on the board
/screen/SCREEN_G4: U3.16 (PD10); also elsewhere on the board
/screen/SCREEN_G5: U3.17 (PD11); also elsewhere on the board
/screen/SCREEN_HS: U3.28 (PD20); also elsewhere on the board
/screen/SCREEN_PCLK: U3.26 (PD18); also elsewhere on the board
/screen/SCREEN_R0: U3.7 (PD1); also elsewhere on the board
/screen/SCREEN_R1: U3.8 (PD2); also elsewhere on the board
/screen/SCREEN_R2: U3.9 (PD3); also elsewhere on the board
/screen/SCREEN_R3: U3.10 (PD4); also elsewhere on the board
/screen/SCREEN_R4: U3.11 (PD5); also elsewhere on the board
/screen/SCREEN_SCL: U3.27 (PD19); also elsewhere on the board
/screen/SCREEN_SDA: U3.45 (PE4); also elsewhere on the board
/screen/SCREEN_VS: U3.29 (PD21); also elsewhere on the board
/soc_f1c/F1C_RST: C30.1, R24.1, U3.70 (RESET)
/soc_f1c/I2C_IRQ: U3.47 (PE2); also elsewhere on the board
/soc_f1c/NAND_CS: U3.60 (PC1); also elsewhere on the board
/soc_f1c/NAND_MISO: U3.61 (PC2); also elsewhere on the board
/soc_f1c/NAND_MOSI: U3.62 (PC3); also elsewhere on the board
/soc_f1c/OSC_IN1: C29.1, U3.52 (HOSCO), Y1.1
/soc_f1c/OSC_IN2: C31.1, U3.51 (HOSCI), Y1.3
/soc_f1c/SDIO_CLK: U3.56 (PF2); also elsewhere on the board
/soc_f1c/SDIO_CMD: U3.55 (PF3); also elsewhere on the board
/soc_f1c/SDIO_D0: U3.57 (PF1); also elsewhere on the board
/soc_f1c/SDIO_D1: U3.58 (PF0); also elsewhere on the board
/soc_f1c/SDIO_D2: U3.53 (PF5); also elsewhere on the board
/soc_f1c/SDIO_D3: U3.54 (PF4); also elsewhere on the board
/soc_f1c/SVREF: R25.1, R26.2, U3.33 (SVREF)
/soc_f1c/TV_VRA1: C13.1, C15.1, U3.75 (TV_VRN)
/soc_f1c/TV_VRA2: C15.2, C16.1, U3.76 (TV_VRP)
/soc_f1c/VRA1: C49.1, R37.2, U3.81 (VRA1)
/soc_f1c/VRA2: C50.1, R63.2, U3.83 (VRA2)
/soc_peripherals/NAND_CLK: U3.59 (PC0); also elsewhere on the board
GND: C13.2, C14.2, C16.2, C17.2, C18.2, C19.2, C20.2, C21.2, C22.2, C23.2, C24.2, C25.2, C26.2, C27.2, C28.2, C29.2, C30.2, C31.2, C40.1, C41.1, C42.1, C43.1, C44.1, C49.2, C50.2, R26.1, R37.1, R63.1, U3.74 (TVGND), U3.82 (AGND), U3.89 (GND); also elsewhere on the board
unnamed: C44.2, U3.84 (FMINL)
unnamed: C43.2, U3.85 (FMINR)
unnamed: C40.2, U3.2 (HPCOMFB)
unnamed: C42.2, U3.86 (LINL)
unnamed: C41.2, U3.87 (MICIN)

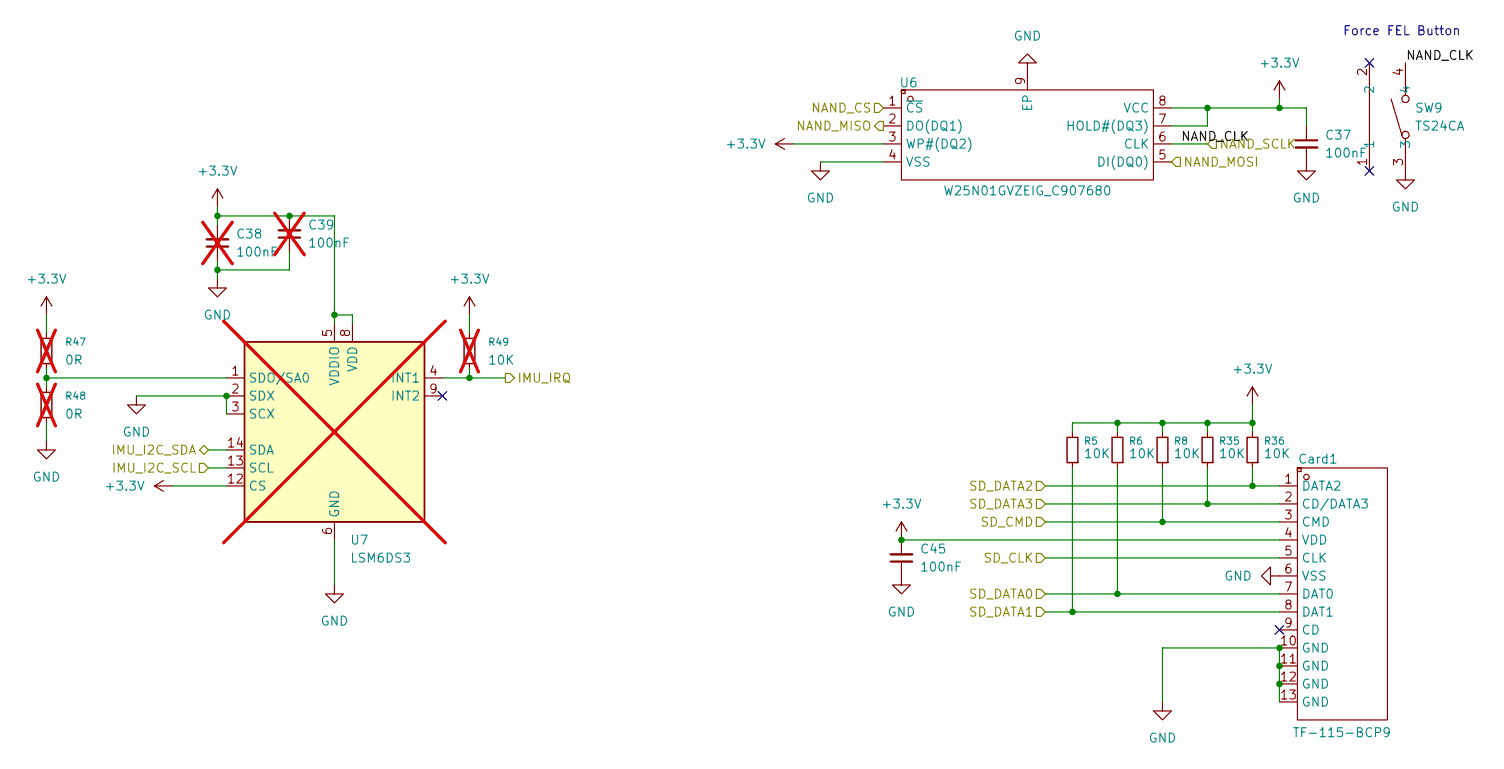
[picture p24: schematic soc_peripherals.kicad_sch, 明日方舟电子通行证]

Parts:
C37, C45: 100nF; C_0603_1608Metric
C38, C39: 100nF; C_0603_1608Metric; not fitted
Card1: TF-115-BCP9; TF-SMD_TF-115-BCP9; LCSC Part C720505
R5, R6, R8, R35, R36: 10K; R_0603_1608Metric
R47, R48: 0R; R_0603_1608Metric; not fitted
R49: 10K; R_0603_1608Metric; not fitted
SW9: TS24CA; SW-SMD_TS24CA; LCSC Part C393942
U6: W25N01GVZEIG_C907680; WSON-8_L8.0-W6.10-P1.27-BL-EP; LCSC Part C907680
U7: LSM6DS3; LGA-14_3x2.5mm_P0.5mm_LayoutBorder3x4y; not fitted

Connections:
+3.3V: C37.1, C38.2, C39.2, C45.2, Card1.4 (VDD), R5.2, R6.2, R8.2, R35.2, R36.2, R47.2, R49.2, U6.3 (WP#(DQ2)), U6.7 (HOLD#(DQ3)), U6.8 (VCC), U7.5 (VDDIO), U7.8 (VDD), U7.12 (CS); also elsewhere on the board
/TWI0_SCL: U7.13 (SCL); also elsewhere on the board
/TWI0_SDA: U7.14 (SDA); also elsewhere on the board
/soc_f1c/I2C_IRQ: R49.1, U7.4 (INT1); also elsewhere on the board
/soc_f1c/NAND_CS: U6.1 (~CS); also elsewhere on the board
/soc_f1c/NAND_MISO: U6.2 (DO(DQ1)); also elsewhere on the board
/soc_f1c/NAND_MOSI: U6.5 (DI(DQ0)); also elsewhere on the board
/soc_f1c/SDIO_CLK: Card1.5 (CLK); also elsewhere on the board
/soc_f1c/SDIO_CMD: Card1.3 (CMD), R8.1; also elsewhere on the board
/soc_f1c/SDIO_D0: Card1.7 (DAT0), R6.1; also elsewhere on the board
/soc_f1c/SDIO_D1: Card1.8 (DAT1), R5.1; also elsewhere on the board
/soc_f1c/SDIO_D2: Card1.1 (DATA2), R36.1; also elsewhere on the board
/soc_f1c/SDIO_D3: Card1.2 (CD/DATA3), R35.1; also elsewhere on the board
/soc_peripherals/NAND_CLK: SW9.4, U6.6 (CLK); also elsewhere on the board
GND: C37.2, C38.1, C39.1, C45.1, Card1.6 (VSS), Card1.10 (GND), Card1.11 (GND), Card1.12 (GND), Card1.13 (GND), R48.1, SW9.3, U6.4 (VSS), U6.9 (EP), U7.2 (SDX), U7.3 (SCX), U7.6 (GND), U7.7 (GND); also elsewhere on the board
unnamed: R47.1, R48.2, U7.1 (SDO/SA0)

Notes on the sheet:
Force FEL Button

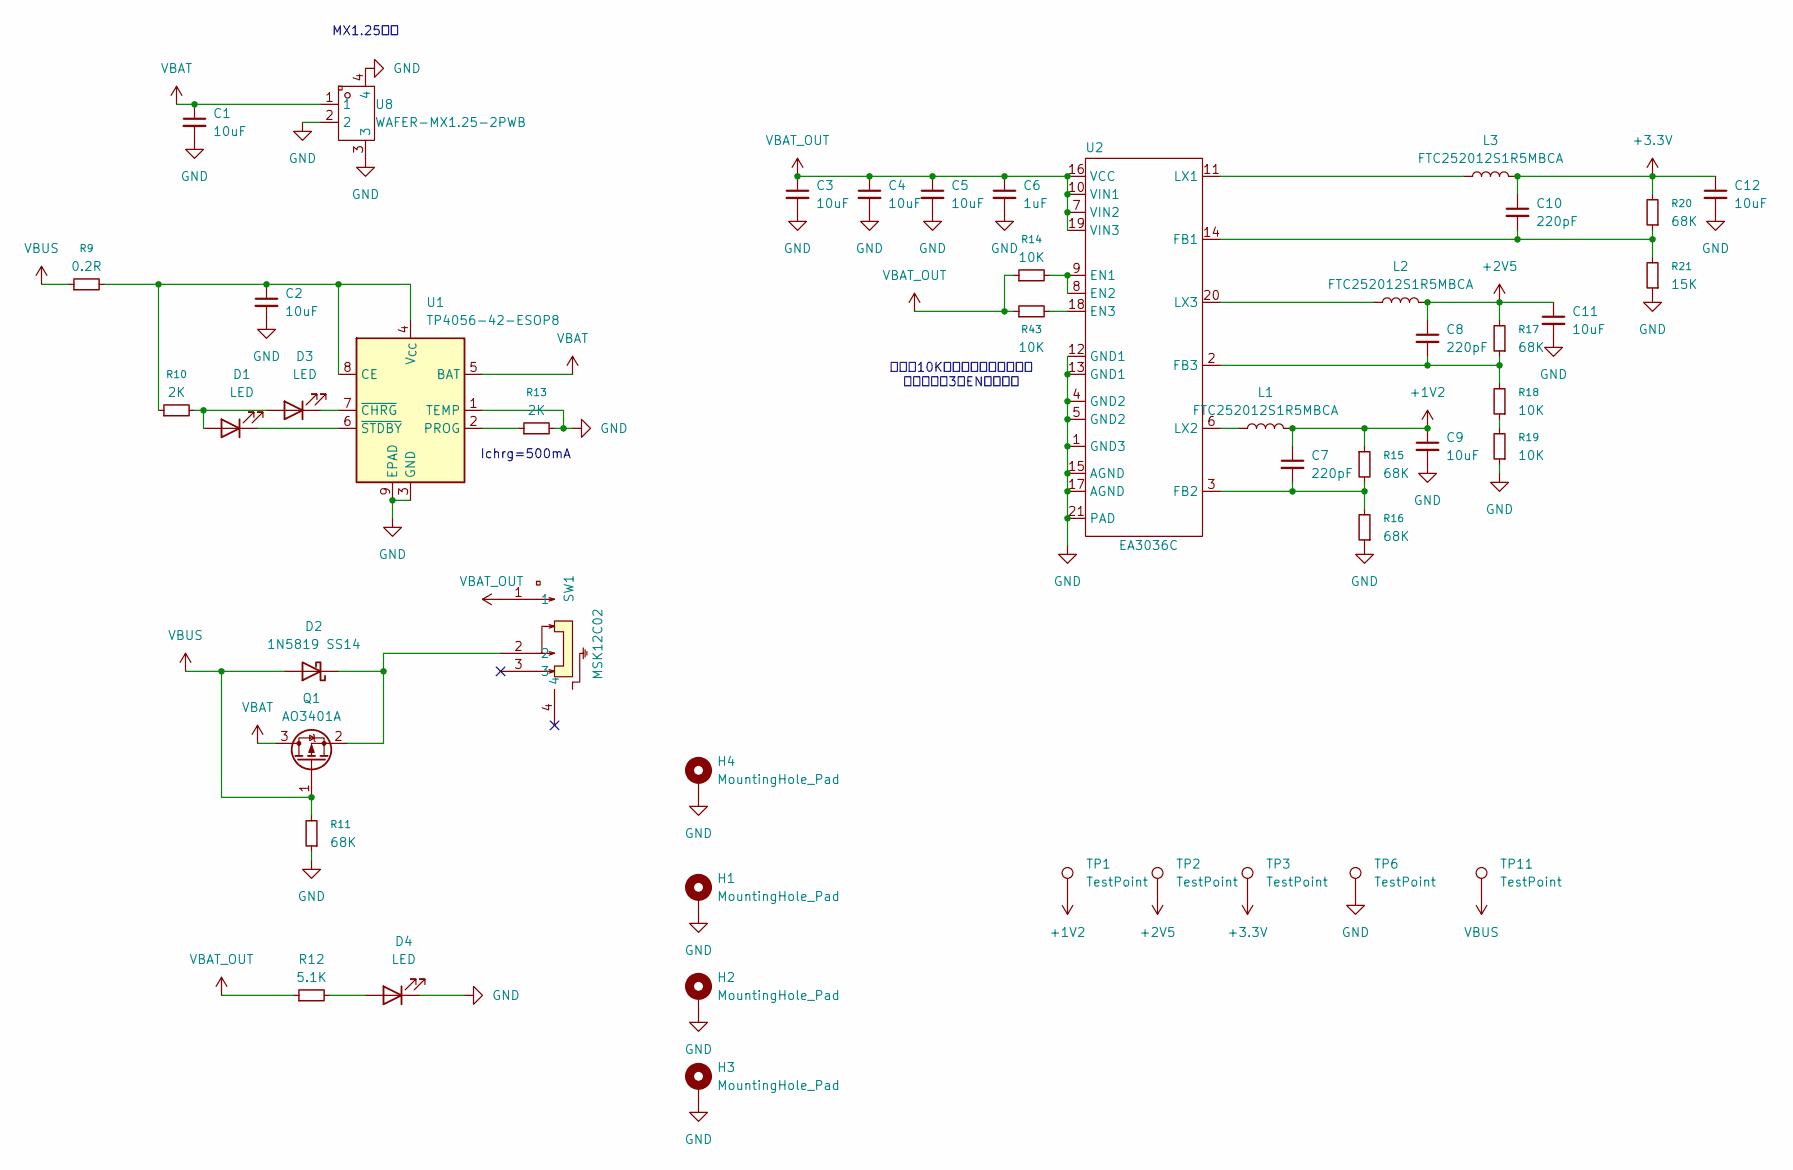
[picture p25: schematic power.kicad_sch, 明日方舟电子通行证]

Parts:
C1, C2, C3, C4, C5, C9, C11, C12: 10uF; C_0603_1608Metric
C6: 1uF; C_0603_1608Metric
C7, C8, C10: 220pF; C_0603_1608Metric
D1, D3, D4: LED; LED_0805_2012Metric
D2: 1N5819 SS14; D_SOD-323
H1, H2, H3, H4: MountingHole_Pad; MountingHole_2.7mm_M2.5_DIN965_Pad
L1, L2, L3: FTC252012S1R5MBCA; IND-SMD_L2.5-W2.0-VLS252012CX-150M
Q1: AO3401A; SOT-23
R9: 0.2R; R_0805_2012Metric
R10, R13: 2K; R_0603_1608Metric
R11, R15, R16, R17, R20: 68K; R_0603_1608Metric
R12: 5.1K; R_0603_1608Metric
R14, R18, R19, R43: 10K; R_0603_1608Metric
R21: 15K; R_0603_1608Metric
SW1: MSK12C02; SW-TH_MSK12C02; LCSC Part C431540
TP1, TP2, TP3, TP6, TP11: TestPoint; TestPoint_Pad_D1.5mm
U1: TP4056-42-ESOP8; SOIC-8-1EP_3.9x4.9mm_P1.27mm_EP2.41x3.3mm_ThermalVias
U2: EA3036C; WQFN-20_L3.0-W3.0-P0.40-BL-EP; LCSC Part C570857
U8: WAFER-MX1.25-2PWB; CONN-SMD_2P-P1.25_XUNPU_WAFER-MX1.25-2PWB; LCSC Part C3029359

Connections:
+1V2: C7.1, C9.1, L1.2, R15.1, TP1.1; also elsewhere on the board
+2V5: C8.1, C11.1, L2.2, R17.2, TP2.1; also elsewhere on the board
+3.3V: C10.1, C12.1, L3.2, R20.2, TP3.1; also elsewhere on the board
GND: C1.2, C2.2, C3.2, C4.2, C5.2, C6.2, C9.2, C11.2, C12.2, D4.1 (K), H1.1, H2.1, H3.1, H4.1, R11.1, R13.2, R16.1, R19.1, R21.1, TP6.1, U1.1 (TEMP), U1.3 (GND), U1.9 (EPAD), U2.1 (GND3), U2.4 (GND2), U2.5 (GND2), U2.12 (GND1), U2.13 (GND1), U2.15 (AGND), U2.17 (AGND), U2.21 (PAD), U8.2, U8.3, U8.4; also elsewhere on the board
unnamed: D1.2 (A), D3.2 (A), R10.2
unnamed: D1.1 (K), U1.6 (~STDBY)
unnamed: D2.1 (K), Q1.2 (S), SW1.2
unnamed: D3.1 (K), U1.7 (~CHRG)
unnamed: D4.2 (A), R12.2
unnamed: R18.1, R19.2
unnamed: C2.1, R9.2, R10.1, U1.4 (V_{CC}), U1.8 (CE)
unnamed: R13.1, U1.2 (PROG)
unnamed: R14.2, U2.8 (EN2), U2.9 (EN1)
unnamed: R43.2, U2.18 (EN3)
unnamed: C10.2, R20.1, R21.2, U2.14 (FB1)
unnamed: C7.2, R15.2, R16.2, U2.3 (FB2)
unnamed: C8.2, R17.1, R18.2, U2.2 (FB3)
unnamed: L3.1, U2.11 (LX1)
unnamed: L1.1, U2.6 (LX2)
unnamed: L2.1, U2.20 (LX3)
VBAT: C1.1, Q1.3 (D), U1.5 (BAT), U8.1
VBAT_OUT: C3.1, C4.1, C5.1, C6.1, R12.1, R14.1, R43.1, SW1.1, U2.7 (VIN2), U2.10 (VIN1), U2.16 (VCC), U2.19 (VIN3); also elsewhere on the board
VBUS: D2.2 (A), Q1.1 (G), R9.1, R11.2, TP11.1; also elsewhere on the board

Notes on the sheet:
MX1.25端子
此处双10K电阻是为了走线方便。 和单电阻带3个EN效果一致
Ichrg=500mA

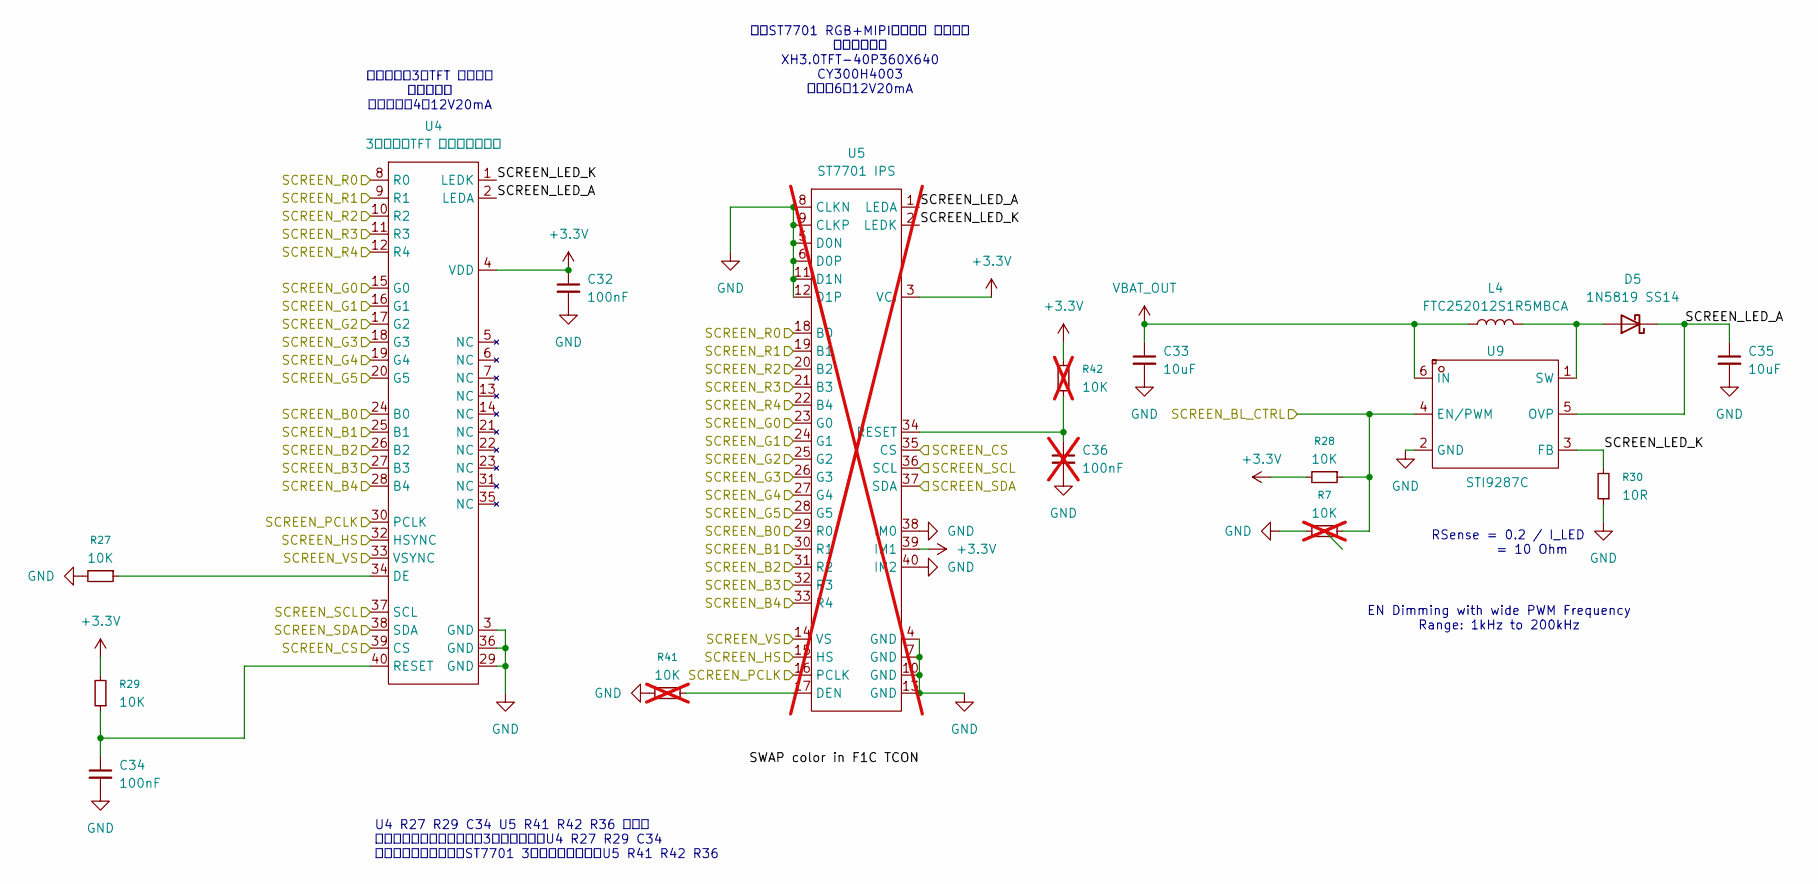
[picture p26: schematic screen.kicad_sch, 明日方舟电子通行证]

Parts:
C32, C34: 100nF; C_0603_1608Metric
C33, C35: 10uF; C_0603_1608Metric
C36: 100nF; C_0603_1608Metric; not fitted
D5: 1N5819 SS14; D_SOD-323
L4: FTC252012S1R5MBCA; IND-SMD_L2.5-W2.0-VLS252012CX-150M
R7, R41, R42: 10K; R_0603_1608Metric; not fitted
R27, R28, R29: 10K; R_0603_1608Metric
R30: 10R; R_0603_1608Metric
U4: 3寸液晶屏TFT 全新无定义资料; Hirose_FH12-40S-0.5SH_1x40-1MP_P0.50mm_Horizontal
U5: ST7701 IPS; Hirose_FH12-40S-0.5SH_1x40-1MP_P0.50mm_Horizontal; not fitted
U9: STI9287C; SOT-23-6_L2.9-W1.6-P0.95-LS2.8-BL; LCSC Part C2985059

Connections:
+3.3V: C32.1, R28.2, R29.2, R42.2, U4.4 (VDD), U5.3 (VCI), U5.39 (IM1); also elsewhere on the board
/screen/SCREEN_B0: U4.24 (B0), U5.29 (R0); also elsewhere on the board
/screen/SCREEN_B1: U4.25 (B1), U5.30 (R1); also elsewhere on the board
/screen/SCREEN_B2: U4.26 (B2), U5.31 (R2); also elsewhere on the board
/screen/SCREEN_B3: U4.27 (B3), U5.32 (R3); also elsewhere on the board
/screen/SCREEN_B4: U4.28 (B4), U5.33 (R4); also elsewhere on the board
/screen/SCREEN_BL_CTRL: R7.1, R28.1, U9.4 (EN/PWM); also elsewhere on the board
/screen/SCREEN_CS: U4.39 (CS), U5.35 (CS); also elsewhere on the board
/screen/SCREEN_G0: U4.15 (G0), U5.23 (G0); also elsewhere on the board
/screen/SCREEN_G1: U4.16 (G1), U5.24 (G1); also elsewhere on the board
/screen/SCREEN_G2: U4.17 (G2), U5.25 (G2); also elsewhere on the board
/screen/SCREEN_G3: U4.18 (G3), U5.26 (G3); also elsewhere on the board
/screen/SCREEN_G4: U4.19 (G4), U5.27 (G4); also elsewhere on the board
/screen/SCREEN_G5: U4.20 (G5), U5.28 (G5); also elsewhere on the board
/screen/SCREEN_HS: U4.32 (HSYNC), U5.15 (HS); also elsewhere on the board
/screen/SCREEN_LED_A: C35.1, D5.1 (K), U4.2 (LEDA), U5.1 (LEDA), U9.5 (OVP)
/screen/SCREEN_LED_K: R30.2, U4.1 (LEDK), U5.2 (LEDK), U9.3 (FB)
/screen/SCREEN_PCLK: U4.30 (PCLK), U5.16 (PCLK); also elsewhere on the board
/screen/SCREEN_R0: U4.8 (R0), U5.18 (B0); also elsewhere on the board
/screen/SCREEN_R1: U4.9 (R1), U5.19 (B1); also elsewhere on the board
/screen/SCREEN_R2: U4.10 (R2), U5.20 (B2); also elsewhere on the board
/screen/SCREEN_R3: U4.11 (R3), U5.21 (B3); also elsewhere on the board
/screen/SCREEN_R4: U4.12 (R4), U5.22 (B4); also elsewhere on the board
/screen/SCREEN_SCL: U4.37 (SCL), U5.36 (SCL); also elsewhere on the board
/screen/SCREEN_SDA: U4.38 (SDA), U5.37 (SDA); also elsewhere on the board
/screen/SCREEN_VS: U4.33 (VSYNC), U5.14 (VS); also elsewhere on the board
GND: C32.2, C33.2, C34.2, C35.2, C36.2, R7.2, R27.2, R30.1, R41.2, U4.3 (GND), U4.29 (GND), U4.36 (GND), U5.4 (GND), U5.5 (D0N), U5.6 (D0P), U5.7 (GND), U5.8 (CLKN), U5.9 (CLKP), U5.10 (GND), U5.11 (D1N), U5.12 (D1P), U5.13 (GND), U5.38 (IM0), U5.40 (IM2), U9.2 (GND); also elsewhere on the board
unnamed: D5.2 (A), L4.2, U9.1 (SW)
unnamed: R27.1, U4.34 (DE)
unnamed: C34.1, R29.1, U4.40 (RESET)
unnamed: R41.1, U5.17 (DEN)
unnamed: C36.1, R42.1, U5.34 (RESET)
VBAT_OUT: C33.1, L4.1, U9.6 (IN); also elsewhere on the board

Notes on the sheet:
RSense = 0.2 / I_LED = 10 Ohm
通用ST7701 RGB+MIPI屏幕接口 上接！！ 已测试型号： XH3.0TFT-40P360X640 CY300H4003 背光：6串12V20mA
EN Dimming with wide PWM Frequency Range: 1kHz to 200kHz
U4 R27 R29 C34 U5 R41 R42 R36 说明： 若购买的屏幕是老王电子的3元屏，只贴装U4 R27 R29 C34 若购买的屏幕是通用的ST7701 3寸钢壳屏，只贴装U5 R41 R42 R36
老王电子的3元TFT 下接！！ （已断货） 此款背光为4串12V20mA

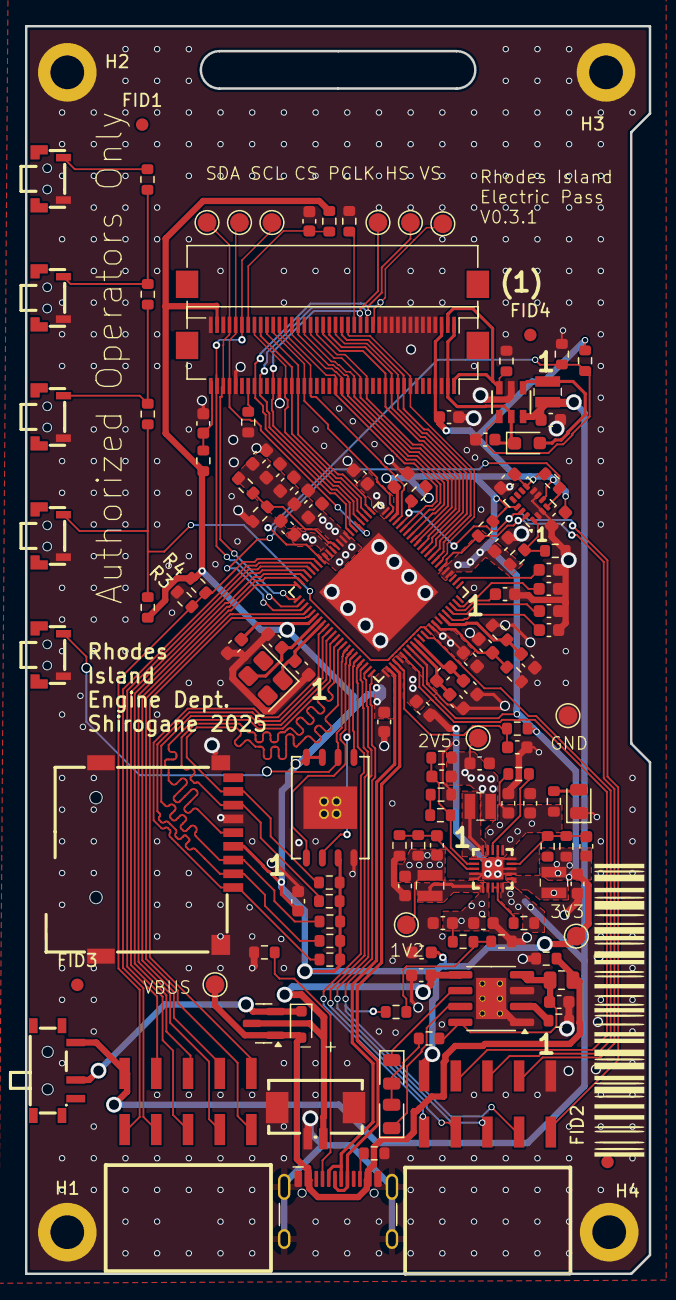
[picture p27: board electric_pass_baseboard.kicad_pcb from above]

Board: 2 copper layers, 50.0 x 100.0 mm, 143 parts (0 on the bottom side), 104 nets.

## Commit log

2025-11-18 inital commit with version 0.2
    [btn_ladder.kicad_sch, electric_pass_baseboard.kicad_pcb, electric_pass_baseboard.kicad_sch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]
2025-11-29 change hole size in QFN EP for a better solder flow.
    [electric_pass_baseboard.kicad_pcb]
2025-12-06 Change file structure
    [/] 大改文件结构，使其更加简介易用
    [/] 整合文件，使仓库更整齐
    [+] 增加手册，利于新手入门(还在写）
    [btn_ladder.kicad_sch, electric_pass_baseboard.kicad_pcb, electric_pass_baseboard.kicad_sch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]
2025-12-14 Enhance README with specifications and project details
    Updated the README to include detailed specifications and features of the 明日方舟电子通行证 (DevKit version).
2026-01-01 0.5.1 4 layer.
    [btn_ladder.kicad_sch, electric_pass_baseboard.kicad_pcb, electric_pass_baseboard.kicad_sch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]
2026-01-03 V1.0 or 4L final i hope
    [btn_ladder.kicad_sch, electric_pass_baseboard.kicad_pcb, electric_pass_baseboard.kicad_sch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]
2026-01-20 Add note about downloading立创EDA version 0.6
2026-02-01 JLC 0.6.
    [btn_ladder.kicad_sch, electric_pass_baseboard.kicad_pcb, electric_pass_baseboard.kicad_sch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]

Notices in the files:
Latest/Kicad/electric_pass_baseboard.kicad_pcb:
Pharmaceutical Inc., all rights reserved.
